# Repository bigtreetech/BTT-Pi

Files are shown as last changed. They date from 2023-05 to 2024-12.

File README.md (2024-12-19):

# BTT-PI
***The usage and configuration of the OS image is exactly the same as CB1 normal version, Please refer to [here](https://github.com/bigtreetech/cb1) to write and configure the OS image***

# 40 Pin GPIO
***BTT-PI and CB1 40pin gpio are different, Please refer to [here](https://github.com/bigtreetech/CB1#40-pin-gpio) for details***

# BTT-PI FAN Pin 

***BIGTREETECH Pi V1.2 Fan Pin connection
Please refer to [here](https://github.com/bigtreetech/BTT-Pi/blob/master/BIGTREETECH%20Pi%20V1.2%20-%20Board%20Fan%20Pin%20Configuration) for details***

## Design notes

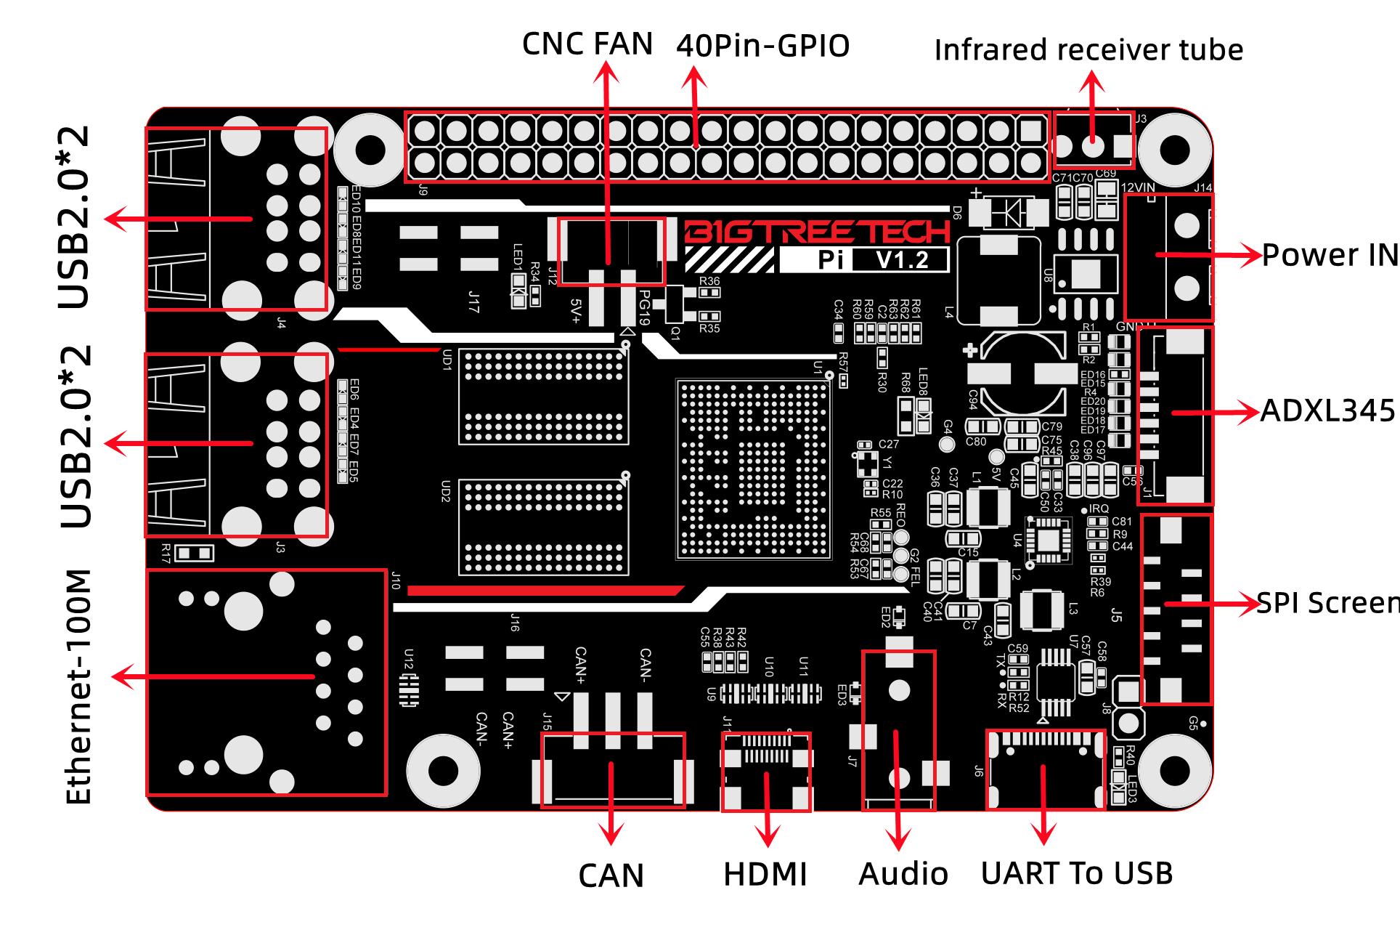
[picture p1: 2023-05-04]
Hardware/Connector.png

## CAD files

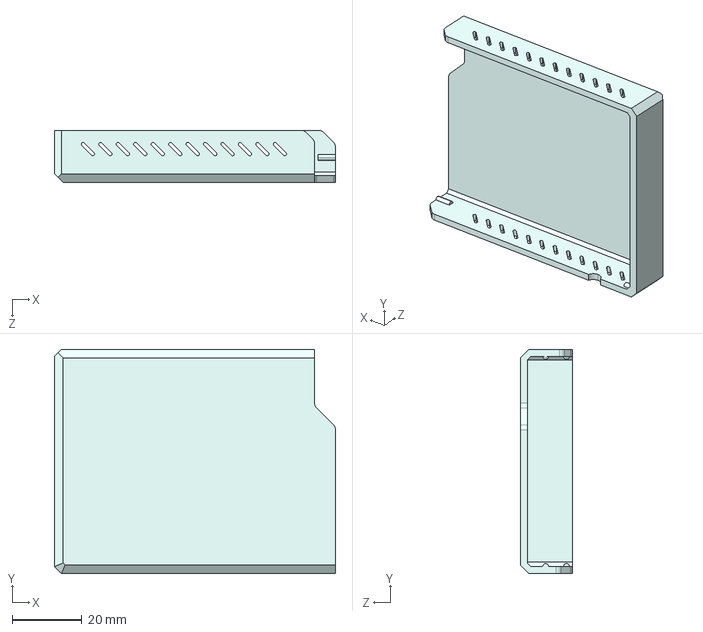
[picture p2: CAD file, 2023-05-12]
3D/BTT_PI_V1.2_Model/step/top_case.STEP
80.5 x 64.2 x 15.0 mm

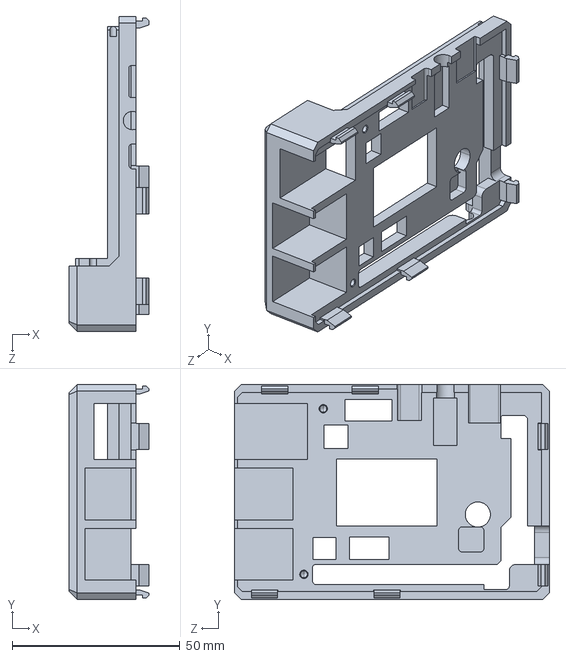
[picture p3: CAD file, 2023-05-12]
3D/BTT_PI_V1.2_Model/step/middle_case.STEP
24.0 x 64.2 x 94.0 mm

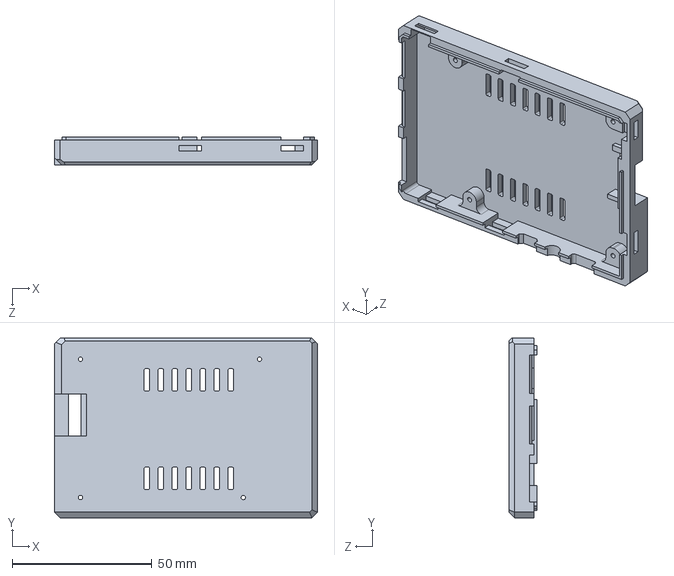
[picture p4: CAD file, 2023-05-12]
3D/BTT_PI_V1.2_Model/step/bottom_case.STEP
94.0 x 64.2 x 10.0 mm

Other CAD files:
3D/BTT_PI_V1.2_Model/stl/bottom_case.STL
3D/BTT_PI_V1.2_Model/stl/middle_case.STL
3D/BTT_PI_V1.2_Model/stl/top_case.STL

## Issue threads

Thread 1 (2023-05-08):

Compatibility with original Raspberry images?

dedekcz, 2023-05-08:
Hello,

Is this board compatible with official Raspberry image?

THX,RH

Tompudex, 2023-05-09:
No, it isn't. the iso that can be used separately for cb modules is also suitable for this

Nbrooks639, 2023-05-19:
i am having issues with reconnecting to mainsail after a simple save and restart from any cfg file. i have to completely shutdown and reboot

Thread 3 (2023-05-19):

Board Fan PG19 pin

So6Rallye, 2023-05-19:
Hi,

I've connected fan on PG19 pin and Klipper doesn't recognize them. Do you have a config to make it work?

error mainsail : Pin 'PG19' is not a valid pin name on mcu 'mcu'

actually I've bypass with one pin on my board but I want to use PG19 pin on BTT PI

[temperature_fan raspberry_pi]
pin: PB6
kick_start_time: 0.8
#shutdown_speed: 0
off_below: 0.1
max_power: 1.0
#fan_speed: 0.6
sensor_type: temperature_host
control: pid
min_temp: -40
max_temp: 85
#max_delta: 5.0
pid_kp: 1.0
pid_ki: 0.5
pid_kd: 2.0
min_speed: 0.1
max_speed: 0.6
target_temp: 38

So6Rallye, 2023-05-19:
If i create and another MCU like this :

[mcu host]
serial: /tmp/klipper_host_mcu

And define :

[temperature_fan raspberry_pi]
pin: host:PG19

I've got message like this : Pin 'PG19' is not a valid pin name on mcu 'host'

So6Rallye, 2023-05-20:
SOLVED !

Message form facebook BTT group [TJ MacLennan]

PG19 is definitely a GPIO pin. It may not be on the 40 pin GPIO header but any input / output pin on the BTT Pi and CB1 is GPIO.

The formula to convert from PG19 to GPIO is:

[(PG - PA)*32] + {Pin Number}

Where PA = 1, PB =2….so PG = 7

So [(7-1)*32] + 19 = 211

Try using GPIO211

The BTT documentation on this is rubbish and lacking.

result :

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

Closed 2023-05-20.

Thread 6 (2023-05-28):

Multiple Printers?

bamboo-eater, 2023-05-28:
Is it possible to connect more than 1 printer to the BTT Pi?  If so are there any documentation on how to do this. Thanks

flavio-costa, 2023-07-31:
yes it is possible, I uploaded klipper using kiauh, there is an option to choose the number of machines to install, it is called instances)

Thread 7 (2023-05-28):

BTT Pi v1.2 case .stl

claidheamohmor, 2023-05-28:
Sajnos a mellékelt kinyomtatható ház elég sok sebből vérzik, a HDMI, audio és tápcsatlakozók lyukainál a "bottom" és "middle" szekcióban kívűl mélyítést kellett készítenem, hogy a csatlakozók műanyag foglalatai elférjenek és a csatlakozók helyesen üljenek be az aljzatokba, illetve az alaplapi JI5 csatlakozó mellyett belül kivágást kellett csinánom, mert vastag a burkolat és nem fér el. A "bottom" fájban az USB csatlakozó melletti bepattintós lyuknál hibás a szerkesztés, illetve a "middle" szekciónak végül a teljes belsejét kivágtam, mert a hűtőborda miatt nem fér el. Sajnos a chip eléggé melegszik, így mindenképpen szükséges a hűtőborda, sőt úgy tűnik, a ventilátort sem lehet megspórolni. Ha valakit érdekel, a módosításokat feltöltöm a Thingiverse-re.

nickdollimount, 2023-06-23:
I also had to make similar modifications. I did the middle cutout for the heatsink as mentioned above, though I didn't have any of the other issues mentioned. The biggest issue for me is a section next to the SD card reader that sits right above one of the tiny components. It wasn't closing right for me so of course my first instinct was to squeeze harder; this piece broke the solder joint of the tiny component. I had to clip out that section of plastic and resolder the component. See the screenshot attached where I circled the offending piece.
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

[BTT Pi Case_Edit.zip](https://github.com/bigtreetech/BTT-Pi/files/11850265/BTT.Pi.Case_Edit.zip)

Escrich, 2024-06-29:
Try mine:

https://www.printables.com/model/927675-caja-para-btt-pi-btt-pi-box-frontal-front

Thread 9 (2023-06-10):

Connecting and spi configuration of SPI ADXL345 on the BTT-PI

Skappa75, 2023-06-10:
Hi, there is a lot of documentation on how to connect an ADXL345 on a CB1 or CM4, and their configuration on Klipper. But I'm in trouble when I connect the BTT-ADXL345 to the BTT-PI by the supplied cable on the dedicated SPI port (page 7 of its manual).
In the pin out what is the right cs_pin number?

Kimmy2000, 2023-06-29:
Hi, this is the setting you require for the BTT-ADXL345 to the BTT-PI

[mcu host]
serial: /tmp/klipper_host_mcu

[adxl345] #BTT PI
cs_pin: host:gpio67
spi_bus: spidev0.0
axes_map: x,y,z

[resonance_tester]
accel_chip: adxl345
accel_per_hz: 70
probe_points: 117.5,117.5,10

In the boardenv.txt uncomment only
overlays=spidev0_0

Skappa75, 2023-06-30:
Hi, thanks for your suggestions but unfortunately it doesn't work by
connecting it via the dedicated ADXL345 port as shown in the BTT-PI manual.
You wrote "cs_pin: host:gpio67" and I noticed that it is from the
40pin-GPIO PC3, you confirm that it is also the right cs.pin of the
dedicated ADXL345 port? Thanks for your help
Skappa

Il giorno gio 29 giu 2023 alle ore 10:59 Kimmy2000 ***@***.***>
ha scritto:

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

Skappa75, 2023-06-30:
I allways recive that error:
"adxl345: spi pins must be on same mcu"

Il giorno gio 29 giu 2023 alle ore 10:59 Kimmy2000 ***@***.***>
ha scritto:

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

Kimmy2000, 2023-06-30:
have you uncommented the SPI like i said here?

In the boardenv.txt uncomment only
overlays=spidev0_0

HYK-HideYourKey, 2023-08-02:
not working for me either... commented spidev0_0 already

UmitBaba, 2023-08-19:
[mcu rpi]
serial: /tmp/klipper_host_mcu

[adxl345]
cs_pin: rpi:gpio67       # I m using fluidd, host:gpio67 doesn't allowed me to write so I tried rpi:gpio67 and just worked.
spi_bus: spidev0.0

[resonance_tester]
accel_chip: adxl345
probe_points:
    155, 155, 20

I m using btt pi v1.2 and this script worked for me. There is one important step, the sd card which plug in to btt pi, you need to plug it your pc and ın the boardenv.txt uncommend overlays=spidev0_0  (remove "#" sign) then dedicated adxl345 port on btt pi works.

Skappa75, 2023-08-19:
Very thanks, I'll try as soon is possible.

Il sab 19 ago 2023, 14:32 UmitBaba ***@***.***> ha scritto:

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

tiagomaricate, 2024-01-23:
What is the name/model of connector in the BTT Pi for the ADXL?

horapet, 2025-04-15:
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

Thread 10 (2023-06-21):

M3 mounting screws cause electrical short

aamott, 2023-06-21:
Issue: There is a positive and negative 12v connection close enough to the mounting screw holes that using an m3 screw instead of an m2.5 screw will cause a short. I found this out when my board started _glowing_ by the mounting hole next to the USB C and smoke came out. Earlier a spark came from the hole on the other side of the SD card.

Since this is a 3D printer board above all and m3 screws fit with minimal resistance, this is a major cause for concern. The fix should be easy though: just add a little more clearance between power and GND.

I would love to recommend this board to my friends, but I can't do that with an easy short right there. Can we get a fix?

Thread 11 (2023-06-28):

Enabling the U2C can adapter

orotecluc, 2023-06-28:
I have bought a BTT-Pi and the U2C pinboard,bt when I assemble them, the PI does not find the canbus...
Is there somewhere an explanation on how to enable the U2C pinboard?

Byourei, 2023-07-06:
Hi, I have a similar problem. I bought a U2C module for the BTT Klipper Pi. Pi does not see U2C when connected, but the LEDs light up. When turned on with BOOT pressed, it can be seen in usb devices, can be flashed. and that's all. we did not find a guide or a manual anywhere. and technical support doesn't know either.

pauluchin, 2023-08-17:
Hi, I also have questions about how to use it. If you could provide more information on how to enable and use it, there isn't much information on the web.

DrKlipper, 2023-09-12:
I had the same issue. Just compile and flash a new firmware and it should work:

- `sudo apt install cmake gcc-arm-none-eabi -y`
- `cd ~`
- `git clone --depth=1 -b stm32g0_support https://github.com/bigtreetech/candleLight_fw`
- `cd ~/candleLight_fw`
- `mkdir build`
- `cd build`
- `cmake .. -DCMAKE_TOOLCHAIN_FILE=../cmake/gcc-arm-none-eabi-8-2019-q3-update.cmake`
- `make budgetcan_fw`
bring CAN Adapter in DFU Mode ... Attach to USB C Cable, hold BOOT button and connect ...
- Flash Adapter : `dfu-util -R -a 0 -s 0x8000000:mass-erase:force -D ~/candleLight_fw/build/budgetcan_fw.bin`

Hoeby, 2024-06-30:
Just to be sure.

Is this for the can adapter v1.0 which is mounted on top of the btt pi? Or for the bigger u2c can adapter V2.1?

orotecluc, 2024-06-30:
For the small v1 that goes on top of pi v1

Verzonden vanaf Outlook voor Android<https://aka.ms/AAb9ysg>
________________________________
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

Hoeby, 2024-06-30:
i ask it here, because there is not much information to find online about this u2c boad.

When i run "lsusb", then i find "OpenMoko, Inc. Geschwister Schneider CAN adapter". It finds the board.
When i run "~/klippy-env/bin/python ~/klipper/scripts/canbus_query.py can0", then i don't see an ID from this board, is this correct? I would say every canbus device must have an ID, also this can adapter.

The reason why, i tried multi can boards to run on the can adapter, but nothing works. Looks like the issue is in the can adapter, but i am not sure

Mati989, 2025-01-17:
Hi. Can someone write what is the full process of flashing this small adapter that goes to the top of pi v1.2 please.I can't find any manual for this adapter.

hiaselhans, 2025-01-23:
@Mati989
https://drklipper.de/doku.php?id=sbcs:61_-_bigtreetech_pi_v1.2_mit_can

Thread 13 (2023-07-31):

i2c overlay

zuverck, 2023-07-31:
Trying to determine which pins on the GPIO are tied to the i2c interface.  There is an overlay and i2c device defined in the BoardEnv.tst file but don't see any documentation or notation in the pins diagram on which pins these are connected to on the GPIO header.

intplus10, 2023-10-17:
It is matching with the standard Pi. I would refer to BTT-Pi user manual page 7, I hope you are searching for this information:
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

EidenPride, 2024-09-08:
> Trying to determine which pins on the GPIO are tied to the i2c interface. There is an overlay and i2c device defined in the BoardEnv.tst file but don't see any documentation or notation in the pins diagram on which pins these are connected to on the GPIO header.

Hi did you find out something about l2c?

BTTJUSTIN, 2024-09-09:
Thanks for making this suggestion. We will discuss it internally and update the documentation if it is approved

Closed 2024-10-18.

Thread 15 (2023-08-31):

Btt pi not working on second day

cheuhyakuroku, 2023-08-31:
Mthe first day it run normal. I config klipper, and print some model file. But second day it not work. Power led is light but nothing happen. Device not turn on,

MarioPerini, 2023-12-22:
same here, waiting for response through mail support

Khalid310, 2024-01-19:
Have you both achieved any solution?

Mine was powered by 24v. The first time its green light was on for a while and then it was suddenly off. Then, each time I power it up, the green light blinks once and totally stops. Tested powering via USB, and it was OK.

MarioPerini, 2024-01-25:
No they declined my refund request on AliExpress. I will. Not buy any BTT products anymore, since I was treated like this. Mine run only for one day at 24V

Escrich, 2024-06-29:
Mine is working since a couple of months ago, without any problem, but I think it's a 5 V fan, not to sure about it now

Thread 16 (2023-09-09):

Fan pin issue

cheuhyakuroku, 2023-09-09:
anyone help me pls 🥹
btt pi v1.2 fan pin issue
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

Escrich, 2024-06-29:
[mcu BTT-Pi]
serial: /tmp/klipper_host_mcu

[temperature_fan BTT-Pi_CPU]  # Temperatura interna del procesador de la BTT Pi
pin: BTT-Pi:gpio211
max_power: 1.0
shutdown_speed: 0
sensor_type: temperature_host
target_temp: 40
max_temp: 85
min_temp: 5
control: pid
pid_kp: 1.0
pid_ki: 0.5
pid_kd: 2.0
off_below: 0.1 # Mantener apagado si la potencia aplicada está por debajo de este valor

Escrich, 2024-06-29:
Check the names you used

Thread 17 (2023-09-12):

Can U2C module not connecting to SB2240

CircuitR, 2023-09-12:
Hi, I have followed the manual for the SB2240, but when I try to flash the SB2240 via Can I get flash error

ERROR:root:Flash Error
Traceback (most recent call last):
  File "/home/biqu/CanBoot/scripts/flash_can.py", line 493, in run_query
    self.cansock.bind((intf,))
OSError: [Errno 19] No such device

During handling of the above exception, another exception occurred:

Traceback (most recent call last):
  File "/home/biqu/CanBoot/scripts/flash_can.py", line 621, in main
    loop.run_until_complete(sock.run_query(intf))
  File "/usr/lib/python3.9/asyncio/base_events.py", line 642, in run_until_complete
    return future.result()
  File "/home/biqu/CanBoot/scripts/flash_can.py", line 495, in run_query
    raise FlashCanError("Unable to bind socket to can0")
FlashCanError: Unable to bind socket to can0

Please advise to fix.

Rivega42, 2025-01-11:
Did you manage to fix it?

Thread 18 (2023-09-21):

Wifi not working when display plugged in

srbjessen, 2023-09-21:
I just got my BTT Pi set up instead of Rpi. Works very well.
But when i plug in my display with Micro HDMI - HDMI cable, the Pi loses connection to wifi.
As soon as i unplug display, the wifi comes back.
Also, the display is heavily flickering and fading in and out.
What could be wrong?

I'm using UART0 (ttyS0) to connect to klipper-mcu.

BTT Pi v1.2
Display: Biqu BX-TFT70

srbjessen, 2023-09-24:
Initial problem solved, turns out the original cable feeding display info and RGB from mainboard was causing interference.
Having removed the cable, the flicker is gone.
But the display is wrong resolution.
I have tried adjusting the "extraargs" in BoardEnv.txt but still wrong

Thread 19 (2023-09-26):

MKS TS35R V2.0

pipech90, 2023-09-26:
Hello everyone I found the[ instructions](https://github.com/Datastore24Kirill/FBGhost6_klipperScreen) for starting the display. There is one but... It is only for ORANGE pi3. Does anyone have the opportunity to fix the driver for our CPU? Or how can it be used?

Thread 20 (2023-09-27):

Enable 1-wire

Puzzl88, 2023-09-27:
How do you enable 1-wire on the BTT-Pi, specifcally for the DS18B20 sensor?

mdvorak, 2023-09-29:
I've created guide how to do that:
https://gist.github.com/mdvorak/2fccca3fa9f76f5a2e11e567797c76d6

Please let me know if it works, or if the guide needs some improvements/fixes. Thanks

Duplicate to https://github.com/bigtreetech/CB1/issues/65 and https://github.com/bigtreetech/CB1/issues/104

Puzzl88, 2023-09-30:
> Please see [bigtreetech/CB1#65 (comment)](https://github.com/bigtreetech/CB1/issues/65#issuecomment-1740552051) for the answer.

biqu@BTT-CB1:~/w1-gpio-cl$ sudo make install
install -m644 w1-gpio-cl.ko /lib/modules/`uname -r`/kernel/drivers/w1/masters
install: cannot stat 'w1-gpio-cl.ko': No such file or directory
make: *** [Makefile:95: install] Error 1

mdvorak, 2023-09-30:
Hmm, maybe I forgot a package, I'll take a look, thanks

Puzzl88, 2023-10-01:
> Hmm, maybe I forgot a package, I'll take a look, thanks

I understood what's the problem.
After LN -s/Lib/Modules/`Uname -r`/Build/Include/Linux W1, you need to execute a command make.

Thanks for the help!

mdvorak, 2023-10-01:
ah, great, I'll update the guide, thanks!

wmetnitz, 2023-10-03:
sorry, i'm a unix newbe - i get the following error:
---
biqu@voron:~/w1-gpio-cl$ **sudo make**
NOTE: ./w1 symlink is already set and will not be updated. Remove it and restart the compilation process in case you want to re-run the kernel sources examination.
NOTE: gen-mast.h was generated
make -C /lib/modules/5.16.17-sun50iw9/build M= modules
make[1]: Entering directory '/usr/src/linux-headers-5.16.17-sun50iw9'
make[2]: *** No rule to make target 'arch/arm64/tools/gen-cpucaps.awk', needed by 'arch/arm64/include/generated/asm/cpucaps.h'.  Stop.
make[1]: *** [arch/arm64/Makefile:173: archprepare] Error 2
make[1]: Leaving directory '/usr/src/linux-headers-5.16.17-sun50iw9'
make: *** [Makefile:13: all] Error 2

mdvorak, 2023-10-03:
Hmm, that is wierd error :-)

mdvorak, 2023-10-04:
I've managed to reproduce it with latest packages, maybe it was caused by some recent system update, I'll investigate it.

mdvorak, 2023-10-04:
@wmetnitz Found it.
`make` needs to be run without `sudo`, for some reason, it messes up env vars and compilation fails to find some files. Also for the compilation itself, sudo should not be really needed.
Guide updated.

_note: `sudo -E make` seems to work file too.`

mdvorak, 2023-10-04:
That was entirely mistake on my side, sorry!
```
echo 'options w1-gpio-cl m1="gdt:71"' | sudo tee /etc/modprobe.d/w1-gpio-cl.conf
echo 'w1-gpio-cl' | sudo tee /etc/modules-load.d/w1-gpio-cl.conf
```
I needed a tester, thanks

wmetnitz, 2023-10-04:
Hi Michal,
thanks, but it doesn't work:

biqu@voron:~/w1-gpio-cl$ echo 'options w1-gpio-cl m1="gdt:71"' | sudo tee /etc/modprobe.d/w1-gpio-cl.conf
options w1-gpio-cl m1="gdt:71"
biqu@voron:~/w1-gpio-cl$ echo 'w1-gpio-cl' | sudo tee /etc/modules-load.d/w1-gpio-cl.conf
w1-gpio-cl
biqu@voron:~/w1-gpio-cl$ sudo modprobe w1-gpio-cl
modprobe: ERROR: could not insert 'w1_gpio_cl': Exec format error
biqu@voron:~/w1-gpio-cl$

wmetnitz, 2023-10-04:
Hi, thanks for your help, but it doesn’t work…

***@***.***:~/w1-gpio-cl$ echo 'options w1-gpio-cl m1="gdt:71"' | sudo tee /etc/modprobe.d/w1-gpio-cl.conf

options w1-gpio-cl m1="gdt:71"

***@***.***:~/w1-gpio-cl$ echo 'w1-gpio-cl' | sudo tee /etc/modules-load.d/w1-gpio-cl.conf

w1-gpio-cl

***@***.***:~/w1-gpio-cl$ sudo modprobe w1-gpio-cl

modprobe: ERROR: could not insert 'w1_gpio_cl': Exec format error

***@***.***:~/w1-gpio-cl$

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

math-milan, 2025-01-02:
Hi, I have trouble finding the kernel headers. I have used the new release with the 6.6.66 Kernel but i only find legacy headers with apt. Do i have to get the headers from the kernel direktly ( from source )?

I am trying this at the moment but so far no luck. Thangs for sugestions

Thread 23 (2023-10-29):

launch BC1 on BTT PI from USB

stepand70, 2023-10-29:
Is it possible to teach BTT Pi to run from USB?

idontknowtom, 2023-11-30:
@stepand70 You mean to run from a USB drive or SSD?

stepand70, 2023-11-30:
> @stepand70 You mean to run from a USB drive or SSD?

USB

idontknowtom, 2023-11-30:
@stepand70 You have to setup with a micro SD card first. Then transfer system over to USB. But the BOOT partition will stay on the micro SD card so you need to keep the card in the BTT Pi. The CB1 and BTT Pi are essentially clones of the Orange Pi Zero 2.

So follow this [guide](https://jamesachambers.com/orange-pi-zero-2-usb-ssd-boot-guide/) and it will work. You won’t find any better performance with a USB thumb drive. In fact the guide says you’ll get worse performance. I tested as well. USB to M.2 SATA SSD works amazing.

stepand70, 2023-11-30:
> @stepand70 You have to setup with a micro SD card first. Then transfer system over to USB. But the BOOT partition will stay on the micro SD card so you need to keep the card in the BTT Pi. The CB1 and BTT Pi are essentially clones of the Orange Pi Zero 2.
>
> So follow this [guide](https://jamesachambers.com/orange-pi-zero-2-usb-ssd-boot-guide/) and it will work. You won’t find any better performance with a USB thumb drive. In fact the guide says you’ll get worse performance. I tested as well. USB to M.2 SATA SSD works amazing.

thanks for the advice! It's not about performance, it's not convenient to take out the SD card when it's in the case, I make copies of CB1 and klipper every 3 days))

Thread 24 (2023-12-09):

Display not working

killrob, 2023-12-09:
Hi all,
i have a PTTPi and a TFT35SPI V2.1, i've connected them with the ribbon cable provided with  monitor.
Klipper and Klipperscreen are installed but the display is all white.
what i'm doing wrong?
this is an extract from log:
`2023-12-09 14:17:20,514 [functions.py:log_start()] - --------------------KlipperScreen Log Start--------------------
2023-12-09 14:17:20,516 [functions.py:log_start()] - KlipperScreen Version: v0.3.7-10-gdd3b255
2023-12-09 14:17:20,516 [functions.py:log_start()] - Python version: 3.9
2023-12-09 14:17:20,935 [config.py:get_config_file_location()] - Passed config (-c): /home/biqu/KlipperScreen.conf
2023-12-09 14:17:20,937 [config.py:__init__()] - Config path location: /home/biqu/KlipperScreen/ks_includes/defaults.conf
2023-12-09 14:17:21,004 [config.py:__init__()] - Configured printers: [
  {
    "Printer": {
      "moonraker_host": "127.0.0.1",
      "moonraker_port": "7125",
      "moonraker_api_key": ""
    }
  }
]
2023-12-09 14:17:21,348 [config.py:create_translations()] - Selected lang: None OS lang: en_US
2023-12-09 14:17:21,350 [config.py:install_language()] - Using system lang
2023-12-09 14:17:21,352 [config.py:install_language()] - Using lang en
2023-12-09 14:17:21,436 [screen.py:__init__()] - Screen resolution: 1024x768
2023-12-09 14:17:21,442 [KlippyGtk.py:__init__()] - Font size: 23.8 (medium)
2023-12-09 14:17:24,534 [screen.py:set_screenblanking_timeout()] - Changing screen blanking to: 3600
2023-12-09 14:17:24,548 [screen.py:set_screenblanking_timeout()] - Using DPMS
2023-12-09 14:17:24,558 [screen.py:initial_connection()] - Default printer: None
2023-12-09 14:17:24,559 [screen.py:connect_printer()] - Connecting to printer: Printer
2023-12-09 14:17:24,559 [screen.py:_load_panel()] - Loading panel: splash_screen
2023-12-09 14:17:24,705 [screen.py:attach_panel()] - Current panel hierarchy: splash_screen
2023-12-09 14:17:24,721 [KlippyWebsocket.py:connect()] - Attempting to connect
2023-12-09 14:17:24,760 [KlippyRest.py:_do_request()] - Sending request to http://127.0.0.1:7125/server/info
2023-12-09 14:17:24,782 [KlippyRest.py:_do_request()] - Sending request to http://127.0.0.1:7125/access/oneshot_token
2023-12-09 14:17:24,784 [KlippyWebsocket.py:connect()] - Starting websocket thread
2023-12-09 14:17:24,800 [_logging.py:info()] - Websocket connected
2023-12-09 14:17:24,801 [KlippyWebsocket.py:on_open()] - Moonraker Websocket Open
2023-12-09 14:17:25,096 [KlippyRest.py:_do_request()] - Sending request to http://127.0.0.1:7125/server/info
2023-12-09 14:17:25,117 [KlippyRest.py:_do_request()] - Sending request to http://127.0.0.1:7125/server/info
2023-12-09 14:17:25,119 [screen.py:init_printer()] - Moonraker info {'klippy_connected': False, 'klippy_state': 'disconnected', 'components': ['klippy_connection', 'application', 'websockets', 'internal_transport', 'dbus_manager', 'database', 'file_manager', 'klippy_apis', 'secrets', 'template', 'shell_command', 'machine', 'data_store', 'proc_stats', 'job_state', 'job_queue', 'http_client', 'announcements', 'webcam', 'extensions', 'octoprint_compat', 'authorization', 'history', 'update_manager'], 'failed_components': [], 'registered_directories': ['config', 'logs', 'gcodes'], 'warnings': [], 'websocket_count': 1, 'moonraker_version': 'v0.8.0-206-g9ad8fed', 'missing_klippy_requirements': [], 'api_version': [1, 4, 0], 'api_version_string': '1.4.0'}
2023-12-09 14:17:25,138 [KlippyRest.py:_do_request()] - Sending request to http://127.0.0.1:7125/server/webcams/list
2023-12-09 14:17:25,141 [printer.py:configure_cameras()] - Cameras: []
2023-12-09 14:17:25,142 [screen.py:init_printer()] - Klipper not connected
2023-12-09 14:17:28,149 [KlippyRest.py:_do_request()] - Sending request to http://127.0.0.1:7125/server/info
2023-12-09 14:17:28,168 [KlippyRest.py:_do_request()] - Sending request to http://127.0.0.1:7125/server/info
2023-12-09 14:17:28,170 [screen.py:init_printer()] - Moonraker info {'klippy_connected': False, 'klippy_state': 'disconnected', 'components': ['klippy_connection', 'application', 'websockets', 'internal_transport', 'dbus_manager', 'database', 'file_manager', 'klippy_apis', 'secrets', 'template', 'shell_command', 'machine', 'data_store', 'proc_stats', 'job_state', 'job_queue', 'http_client', 'announcements', 'webcam', 'extensions', 'octoprint_compat', 'authorization', 'history', 'update_manager'], 'failed_components': [], 'registered_directories': ['config', 'logs', 'gcodes'], 'warnings': [], 'websocket_count': 1, 'moonraker_version': 'v0.8.0-206-g9ad8fed', 'missing_klippy_requirements': [], 'api_version': [1, 4, 0], 'api_version_string': '1.4.0'}
2023-12-09 14:17:28,187 [KlippyRest.py:_do_request()] - Sending request to http://127.0.0.1:7125/server/webcams/list
2023-12-09 14:17:28,188 [printer.py:configure_cameras()] - Cameras: []
2023-12-09 14:17:28,189 [screen.py:init_printer()] - Klipper not connected
2023-12-09 14:17:31,150 [KlippyRest.py:_do_request()] - Sending request to http://127.0.0.1:7125/server/info
2023-12-09 14:17:31,169 [KlippyRest.py:_do_request()] - Sending request to http://127.0.0.1:7125/server/info
2023-12-09 14:17:31,171 [screen.py:init_printer()] - Moonraker info {'klippy_connected': False, 'klippy_state': 'disconnected', 'components': ['klippy_connection', 'application', 'websockets', 'internal_transport', 'dbus_manager', 'database', 'file_manager', 'klippy_apis', 'secrets', 'template', 'shell_command', 'machine', 'data_store', 'proc_stats', 'job_state', 'job_queue', 'http_client', 'announcements', 'webcam', 'extensions', 'octoprint_compat', 'authorization', 'history', 'update_manager'], 'failed_components': [], 'registered_directories': ['config', 'logs', 'gcodes'], 'warnings': [], 'websocket_count': 1, 'moonraker_version': 'v0.8.0-206-g9ad8fed', 'missing_klippy_requirements': [], 'api_version': [1, 4, 0], 'api_version_string': '1.4.0'}
2023-12-09 14:17:31,189 [KlippyRest.py:_do_request()] - Sending request to http://127.0.0.1:7125/server/webcams/list
2023-12-09 14:17:31,191 [printer.py:configure_cameras()] - Cameras: []
2023-12-09 14:17:31,191 [screen.py:init_printer()] - Klipper not connected
2023-12-09 14:17:34,155 [KlippyRest.py:_do_request()] - Sending request to http://127.0.0.1:7125/server/info
2023-12-09 14:17:34,178 [KlippyRest.py:_do_request()] - Sending request to http://127.0.0.1:7125/server/info
2023-12-09 14:17:34,181 [screen.py:init_printer()] - Moonraker info {'klippy_connected': True, 'klippy_state': 'startup', 'components': ['klippy_connection', 'application', 'websockets', 'internal_transport', 'dbus_manager', 'database', 'file_manager', 'klippy_apis', 'secrets', 'template', 'shell_command', 'machine', 'data_store', 'proc_stats', 'job_state', 'job_queue', 'http_client', 'announcements', 'webcam', 'extensions', 'octoprint_compat', 'authorization', 'history', 'update_manager'], 'failed_components': [], 'registered_directories': ['config', 'logs', 'gcodes'], 'warnings': [], 'websocket_count': 1, 'moonraker_version': 'v0.8.0-206-g9ad8fed', 'missing_klippy_requirements': [], 'api_version': [1, 4, 0], 'api_version_string': '1.4.0'}
2023-12-09 14:17:34,202 [KlippyRest.py:_do_request()] - Sending request to http://127.0.0.1:7125/server/webcams/list
2023-12-09 14:17:34,204 [printer.py:configure_cameras()] - Cameras: []
2023-12-09 14:17:34,241 [KlippyRest.py:_do_request()] - 404 Client Error>>Not Found for url>>http://127.0.0.1:7125/printer/info
2023-12-09 14:17:37,147 [KlippyRest.py:_do_request()] - Sending request to http://127.0.0.1:7125/server/info
2023-12-09 14:17:37,168 [KlippyRest.py:_do_request()] - Sending request to http://127.0.0.1:7125/server/info
2023-12-09 14:17:37,170 [screen.py:init_printer()] - Moonraker info {'klippy_connected': True, 'klippy_state': 'startup', 'components': ['klippy_connection', 'application', 'websockets', 'internal_transport', 'dbus_manager', 'database', 'file_manager', 'klippy_apis', 'secrets', 'template', 'shell_command', 'machine', 'data_store', 'proc_stats', 'job_state', 'job_queue', 'http_client', 'announcements', 'webcam', 'extensions', 'octoprint_compat', 'authorization', 'history', 'update_manager'], 'failed_components': [], 'registered_directories': ['config', 'logs', 'gcodes', 'config_examples', 'docs'], 'warnings': [], 'websocket_count': 1, 'moonraker_version': 'v0.8.0-206-g9ad8fed', 'missing_klippy_requirements': [], 'api_version': [1, 4, 0], 'api_version_string': '1.4.0'}
2023-12-09 14:17:37,186 [KlippyRest.py:_do_request()] - Sending request to http://127.0.0.1:7125/server/webcams/list
2023-12-09 14:17:37,188 [printer.py:configure_cameras()] - Cameras: []
2023-12-09 14:17:37,208 [KlippyRest.py:_do_request()] - Sending request to http://127.0.0.1:7125/printer/info
2023-12-09 14:17:37,332 [KlippyRest.py:_do_request()] - Sending request to http://127.0.0.1:7125/printer/objects/query?configfile
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

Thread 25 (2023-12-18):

Unable to run ADXL345 from 40 GPIO pins

Vicepredator, 2023-12-18:
Hi, i have a BTT-PI V1.2 and i'm trying to wire the ADXL345 sensor to the GPIO pins.

This is my configuration
```
[mcu rpi]
serial: /tmp/klipper_host_mcu

[adxl345]
cs_pin: None
spi_bus: spidev1.2

[resonance_tester]
accel_chip: adxl345
probe_points: 117.5,117.5,10
```

I've wired the sensor as follows
```
VCC -> 3.3V (Yellow pin)
GND -> GND (Black pin)
CS -> PG12
SDO -> PH8
SDA -> PH7
SCL -> PH6
```

I've tried with all the spi_bus in BoardEnv.txt, but nothing, it doesn't work.

Any clue?

Tankpadua, 2024-01-13:
Why use the GPIO pins when the BTT Pi have the SPI port for the ADXL345 sensor?

Vicepredator, 2024-01-14:
Because I would like to use a standard Amazon sensor, and I don't wanna buy the specific connector.

Gurkenfisch, 2024-01-20:
Just connect it via the dedicated SPI port on the BTT-Pi I have just done that and it works.

mrvander18, 2024-02-20:
Yes, but how. There is no pinout that I can find that matches the BTT-Pi User Manual to the ADXL345.

User Manual ADXL345 Port Pinout
5V
GND
PC3
PC0
PC2
PC4

Board Pinout
GND
VCC
CS
INIT1
INIT2
SDO
SDA
SCL

Now the GND and VCC(5v) are easy enough and from GPIO pinout diagrams, one can deduce the INIT pins are ignored. But HOW do the PC pins map to CEO, Serial Data In, Out and Clock?

**User Manual >> Board**
5V >> VCC
GND >> GND
PC3 >> ??
PC0 >> ??
PC2 >> ??
PC4 >> ??

Amazon Generic Board:
https://www.amazon.com/gp/product/B0BXWHTXWT/ref=ppx_yo_dt_b_search_asin_title?ie=UTF8&psc=1

Gurkenfisch, 2024-02-20:
Ok so I have hooked it up via following:

5V >> VCC
GND >> GND
PC3 >> CS
PC0 >> SCL
PC2 >> SDA
PC4 >> SDO

And then in Klipper I have set it up like the following:

[adxl345] #BTT PI
cs_pin: host:gpio67
spi_bus: spidev0.0
axes_map: x,y,z

[resonance_tester]
accel_chip: adxl345
accel_per_hz: 70
probe_points: 60,60,10

I am almost certain that I just followed the normal input shaper install instructions from there. I am not 100% sure though. It works for me with that wiring.

Vicepredator, 2024-03-08:
Thanks, that seems good.

Vicepredator, 2024-03-08:
Thanks, that seems good.

Hajto, 2024-05-28:
I am having the same issue. Connected the board as in the chart above. No luck klipper detecting the adxl tho

Closed 2024-03-08.

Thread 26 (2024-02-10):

Wifi cable connector name?

Tankpadua, 2024-02-10:
I'm looking for an extension cable for mount a external wifi antenna. I brought one bit the connector are too small. I need with one head SMA.
Thanks

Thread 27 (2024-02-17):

Unnecessary LOGO component in every part of the v1.2 step file.

ChrisJones79, 2024-02-17:
The step file takes a very long time, relatively, and I realized that every `Designatorxxx` tag has a sub-part of a text logo, called `LOGO?xxx`.

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

These are made up of letters, shown here:
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

and here:
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

These are in every single part! Please remove them.

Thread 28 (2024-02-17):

PRODUCT WARNING! DO NOT BUY!

MarioPerini, 2024-02-17:
The product died after just ONE DAY of use. As you can see on issues here on github and on other parts of the internet, i'm by far not the only one with the same problem. So i was sure BTT will replace or refund it fairly quick, but i was so wrong.
"Support" if you can call them so, always promises to replay in a few days and then just silence.
After at least 4 contacts I now just give up my money and throw that board away. My time invested in this case is by far more worth than this SBC!
Company doesn't want to replace or refund, with no further explanation. So my conclusion is to stay away from Big Tree Tech if you want high quality or any usable support if something goes wrong.

Be assured i will never ever purchase any BTT product again!

MarioPerini, 2024-02-21:
Now, out of the blue i got a refund... connected to this issue?

Closed 2024-02-21.

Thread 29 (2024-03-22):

BTT Pi v1.2 very odd USB behaviour.

Bunik, 2024-03-22:
Hello,
I just received Btt Pi v1.2 and hooked it up with Octopus Pro and U2C.
Now the problems.
BTT Pi communicates with Octopus ony with the original USB C cable. Any other C cable I have got does not work and lsusb does not show anything.
U2C does not appear on the list even with that cable. I cannot see it.
When connecting one device at the time.
I also tried to hook up the SB2209 / SBB2240 so I can update the firmware. It does not see it and it does not light the ligts on it.
Even when using the same cable as for the Octobus.

Now the fun part. I used any other cable with the U2C, or the SB2209 and it works with my laptop. Windows immedietely sees the device and I can even put them to DFU mode.  All LEDs on both devices also light up correctly.

It looks like a fault of the Pi, but I have no idea how to resolve it. If it is even possible.
Thanks in advance for any advice!

Bunik, 2024-03-23:
Update:
I have been testing this further and sometimes, just sometimes the U2C lit up when I turned on power to the BTT Pi.
After unplugging and plugging it in again to turn it to DFU mode it did light up again.
Turning on/off the PI sometimes helped, sometimes the U2C just flashed diodes for a second.
I wondered if there is something with the 5V line. So I disconnected the Sunon 5V 0.38W (MF25100V2-1000U-A99) fan which did not work on the PI anyway (It works on the Octopus 5V fan though)
And suddenly all the problems went away?  Now I can use all the cables to connec to all the devices at the same time and they stay on even when I re-connect them.

So I plugged the fan in again to reproduce the issue. I cannot reproduce it again. The fan is still off though.

I am baffled what is going on with this. I will keep testing this board later when I full configure Klipper on it to see how it behaves with a heavy load. I will probably have to wire the 5V fan somewhere else to keep the board cool, which is a bit annoying.

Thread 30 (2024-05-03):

Connectors BOM

turdusmerula, 2024-05-03:
Hello, can you provide the reference of the connectors used on the board?

I'm searching for the exact reference of the CAN connector, I can't find it anywhere

idontknowtom, 2024-05-23:
@turdusmerula It isn't easily found but the CAN connector is a JST XH 3P connector. It is slightly different that what you would find on most 3D printer boards but it still has the same functionality / locking mechanism.

I found this in the STEP file and clicked on the connector in Fusion 360.

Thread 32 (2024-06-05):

Accessing GPIO Pins via Python

tpfirman, 2024-06-05:
Hi, I have bought several BTGT Pi v.12 devices. I am using 2 of them as host machines for CNC/Klipper and they are great.

However, I now have a maker project outside of CNC/3d Printing that I would like to use one for, but I need to access the GPIO pins via Python. Specifically, I need to output on 3 pins, and read from at least two.

I can't seem to find how this is done. Can you please let me know the basics of how I can read/write from/to the GPIO pins using python?

bigtreetech, 2024-06-05:
https://pypi.org/project/gpiod/

https://www.klipper3d.org/RPi_microcontroller.html#optional-identify-the-correct-gpiochip <-- From the klipper wiki but still useful in identifying the gpio.

Closed 2024-06-05.

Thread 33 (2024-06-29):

Independent fan control

Escrich, 2024-06-29:
Dear all, I have one of my BTT Pi inside a Klipper machine, working with the code you provided to make the fan run, without any problem, but, I have a concern, when you are developing something, or simply you will not use this BTT-Pi for klipper, the fan remains stopped, and maybe the CPU will become hot, then, from my point of view, could be a great idea to have something similar as the Raspberry pi has, in order to control the fan in a regulated way, directly as a part of the OS, enclosed I send you three pictures in order to explain what I mean:

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

Escrich, 2024-07-03:
Just doing this control, will be a good idea to make a proportional control, instead of the simple on/off control that Raspberry have

PhilippeLafargue, 2024-09-17:
You are right. Actual solution is klipper dependent: fan can be controlled by klipper only.

But fan control should be OS dependent, as it is related to the MCU cooling, klipper running or not. There are existing solutions for Raspberry PI that could be adapted to BTT-PI.

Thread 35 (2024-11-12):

Not working at all, pls help

HelioNM, 2024-11-12:
I purchase a new BTT Pi 1.12.

I followed the instructions, burn the iso provided here to an SD, edit the config to give the SSID and password, insert SD at the BTT and.... Nothing happen, no connection.

I tried to even use a open wifi network, 3 diferent router, even I tried to share the wifi of my phone, nothing happen, the BBT not connect so I can acces it, I dont know even if it is working or not.

The green led is ON and still. I tried to power it using USB-C cable and also using a 12V PSU of my printer. Nothing.

Help pls.

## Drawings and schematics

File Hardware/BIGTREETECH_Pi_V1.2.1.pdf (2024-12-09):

# 深圳市必趣科技有限公司

Title BIGTREETECH_Pi_V1.1 | Design Bron Bai
Size A3 | Document Number 01_Cover Page | Rev V1.1
Date: Tuesday, November 15, 2022 | Sheet 1 of 16

# BIGTREETECH_Pi_V1.2.1

# 深圳市必趣科技3D打印机BTTPi项目

# SOC: _H616 DDR: _D2516ECMDXGJD MODULE: _TL8189FCB DCDC: _AXP313A LDO: _ XC6220B331MR-G

# 深圳市必趣科技有限公司

Title BIGTREETECH_Pi_V1.1 | Design Bron Bai
Size A3 | Document Number 02_Index | Rev V1.1
Date: Tuesday, November 15, 2022 | Sheet of 2 16

# BIGTREETECH_Pi_V1.1_221114

# 01_Cover Page 02_Index 03_Function Block Diagram 04_Revision History 05_SoC_PMU 06_SOC_BT-WIFI 07_SOC_HDMI_ETH_USB_POWER 08_SOC-DDRCTR_LPDDR3 32X1 09_IO-LDO-FAN 10_BT-WIFI_Module 11_USB To UART 12_SoC_TF_CARD 13_HDMI2.0 14_100M-Ethernet 15_HOST-USB 16_AUDIO-VIDEO-IR

# 深圳市必趣科技有限公司

Title BIGTREETECH_Pi_V1.1 | Design Bron Bai
Size A3 | Document Number 03_Function Block Diagram | Rev V1.1
Date: Tuesday, November 15, 2022 | Sheet of

# TL8189FCB

# SDIO1

# 16BIT_256M 24MHz

RJ45
100M

# SPI0

# SCL0

AXP1530A | SDA0

# AP-RESET PWRON

# FEL RECOVERY DBUG_TX DBUG_RX

# DLDO1_3V3/300mA

# ALDO1_1V8/200mA

# LX2_CPU/1.8A

# LX1_GPU+SYS/1.6A

# LX3_DRAM/1.8A

H616

3.3V

# XC6220B331MR-G

# LDO XC6220B331MR-G

# LDO

WIFI | IO-VCC

# PHONE

# DCDC 12VTO5V/3A

# HDMI

MODULE | USB UART TO
DDR3x2 | IR
SPI1 | SPI0
DSI | Acceler

# USB OTG HOSTUSB2

# HOSTUSB1 HOSTUSB3

J7 | J11 | U6 | J6 | J10 | J3 | J4
J5 | J1 | UD1&UD2 | U3 | Y1

12V/2A

U8 | J14
U5 | U2

U4

# 深圳市必趣科技有限公司

Title TREETECH_Pi_V1.1 | Design
| 04_Revision History

# 版本历史

版本 | 日期 | 修改者 | 修改说明 | 批准
V1.0A | 2022.07.05 | Byron Bai | 1. 在CB1_V2.1设计上修改。
V1.0 | 2022.08.01 | Byron Bai | 2. 增加网口，增加HDMI,增加HOST-USB。 3. IO口全部拉出来。 4. 增加SPI屏和加速计接口。 1. 调换WIFI的方向，天线向这USB那边。
V1.1 | 2022.09.01 | Byron Bai | 2. CH340灯接在芯片输出端。 3. 更改ESD5341N的封装。 1.调换WIFI的方向，天线向耳机这边。
Pi V1.1 | 2022.11.14 | Wan gz | 2.CH340供电接在TYPEC输入端。 3.更改WIFI供电 LDO 为 XC6220B331MR-G。 1.PCB优化走线，SCH同步更新文件名 4.取消PG6 PG7 PG8 PG9，更改为PI5 PI6 PI9 PI10。 5.WIFI SDCARD SDIO增加上拉做等长。 6.TF-CARD SDIO做等长。 7.增加WIFI电源滤波和磁珠。 8.增加DCDC电源滤波。 9.增加系统灯。

1V8

3V3

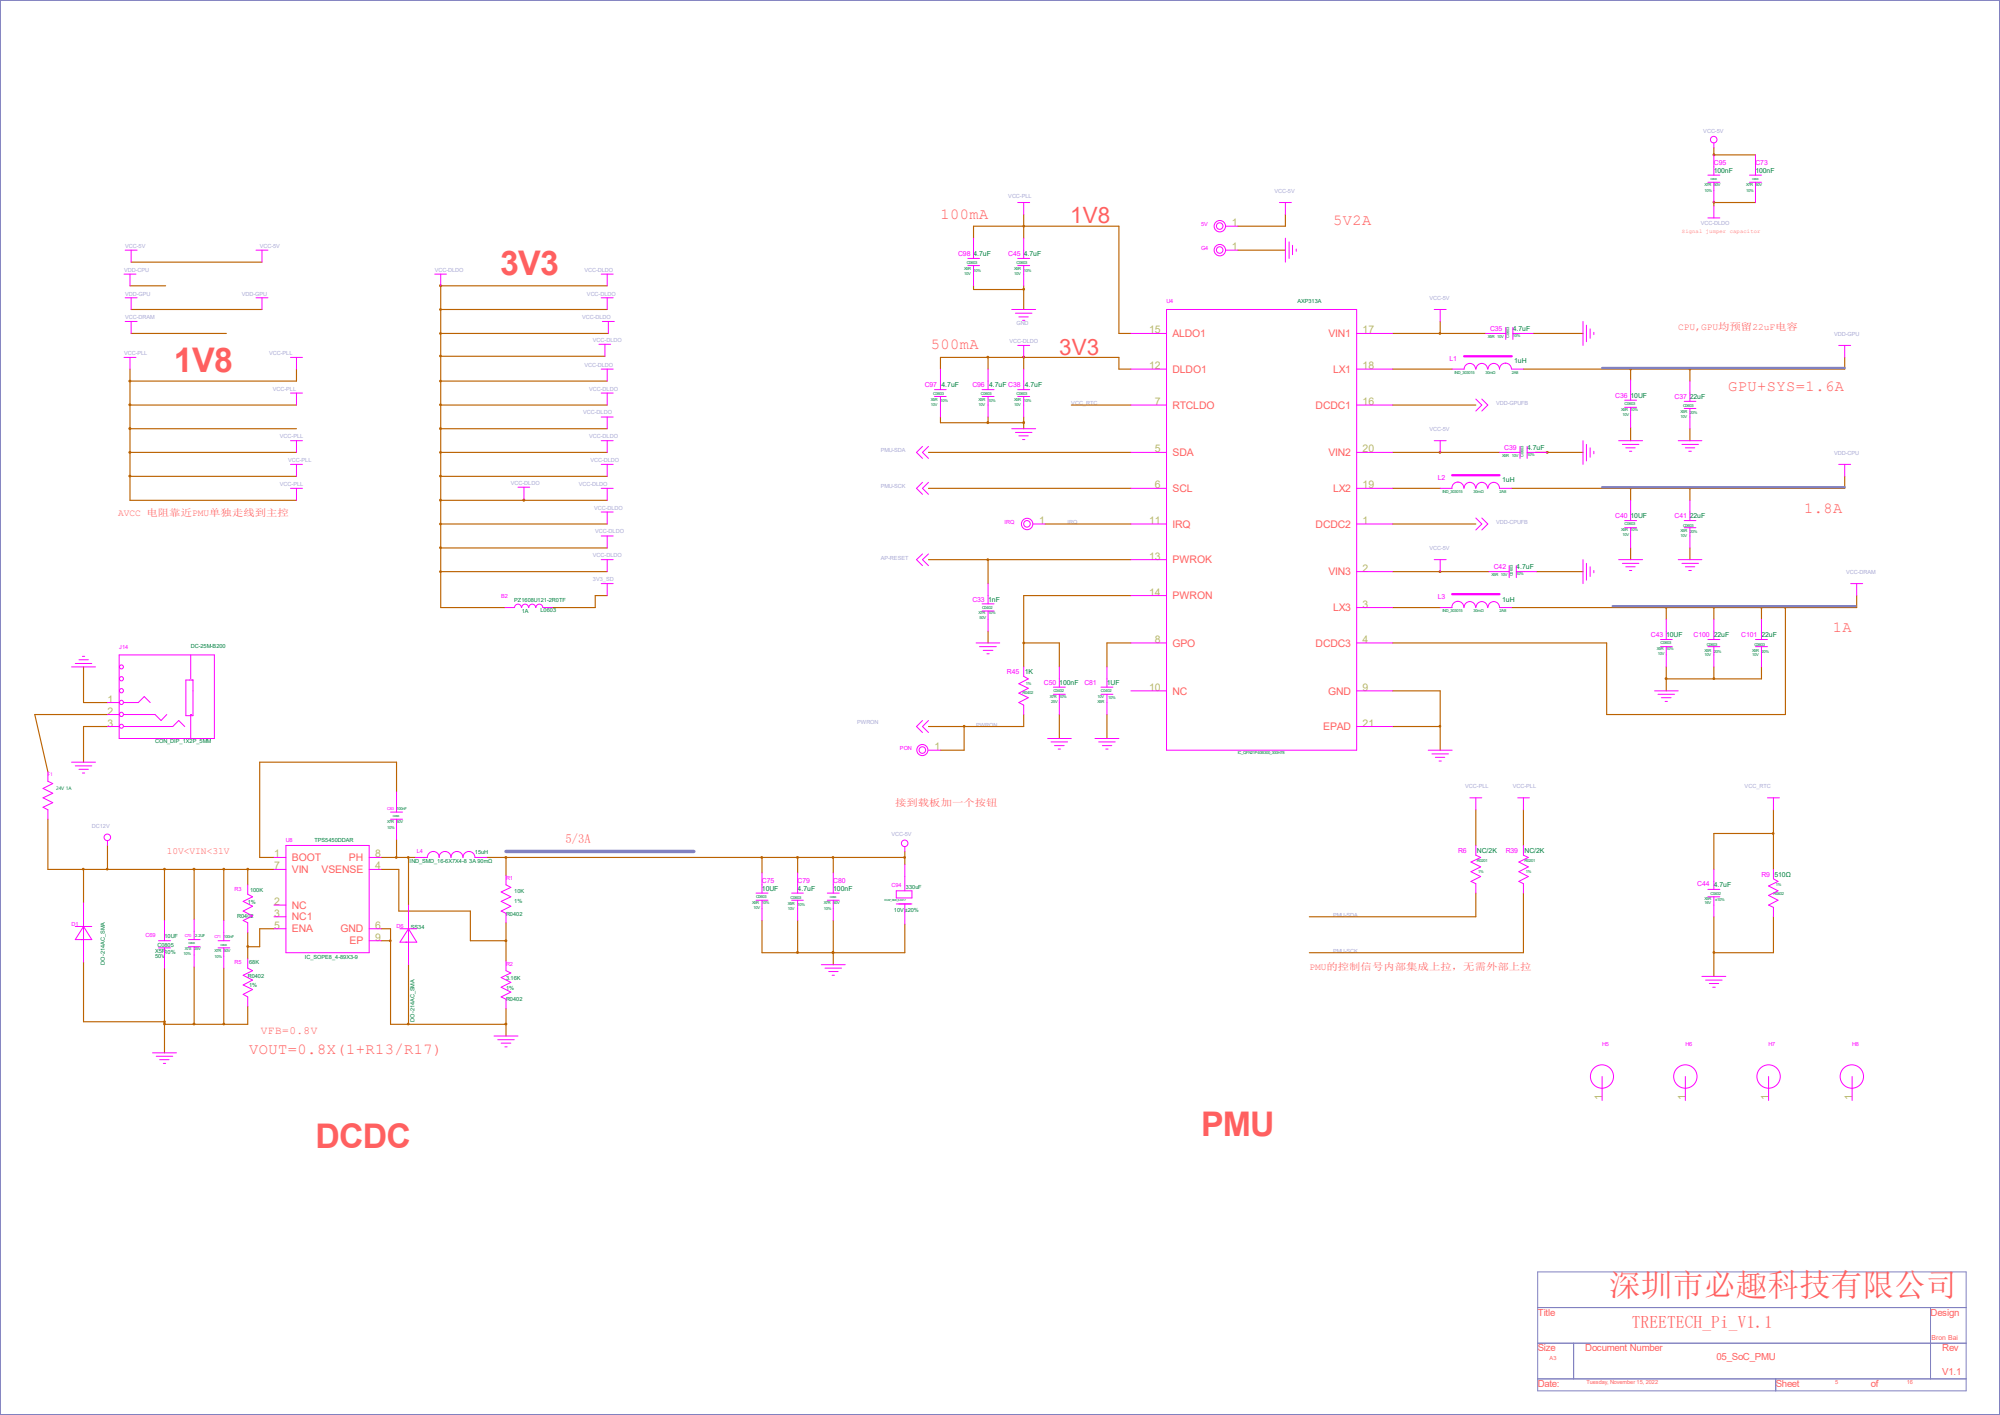
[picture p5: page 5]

Title TREETECH_Pi_V1.1 | Design

05_SoC_PMU

## UART0_DBUG

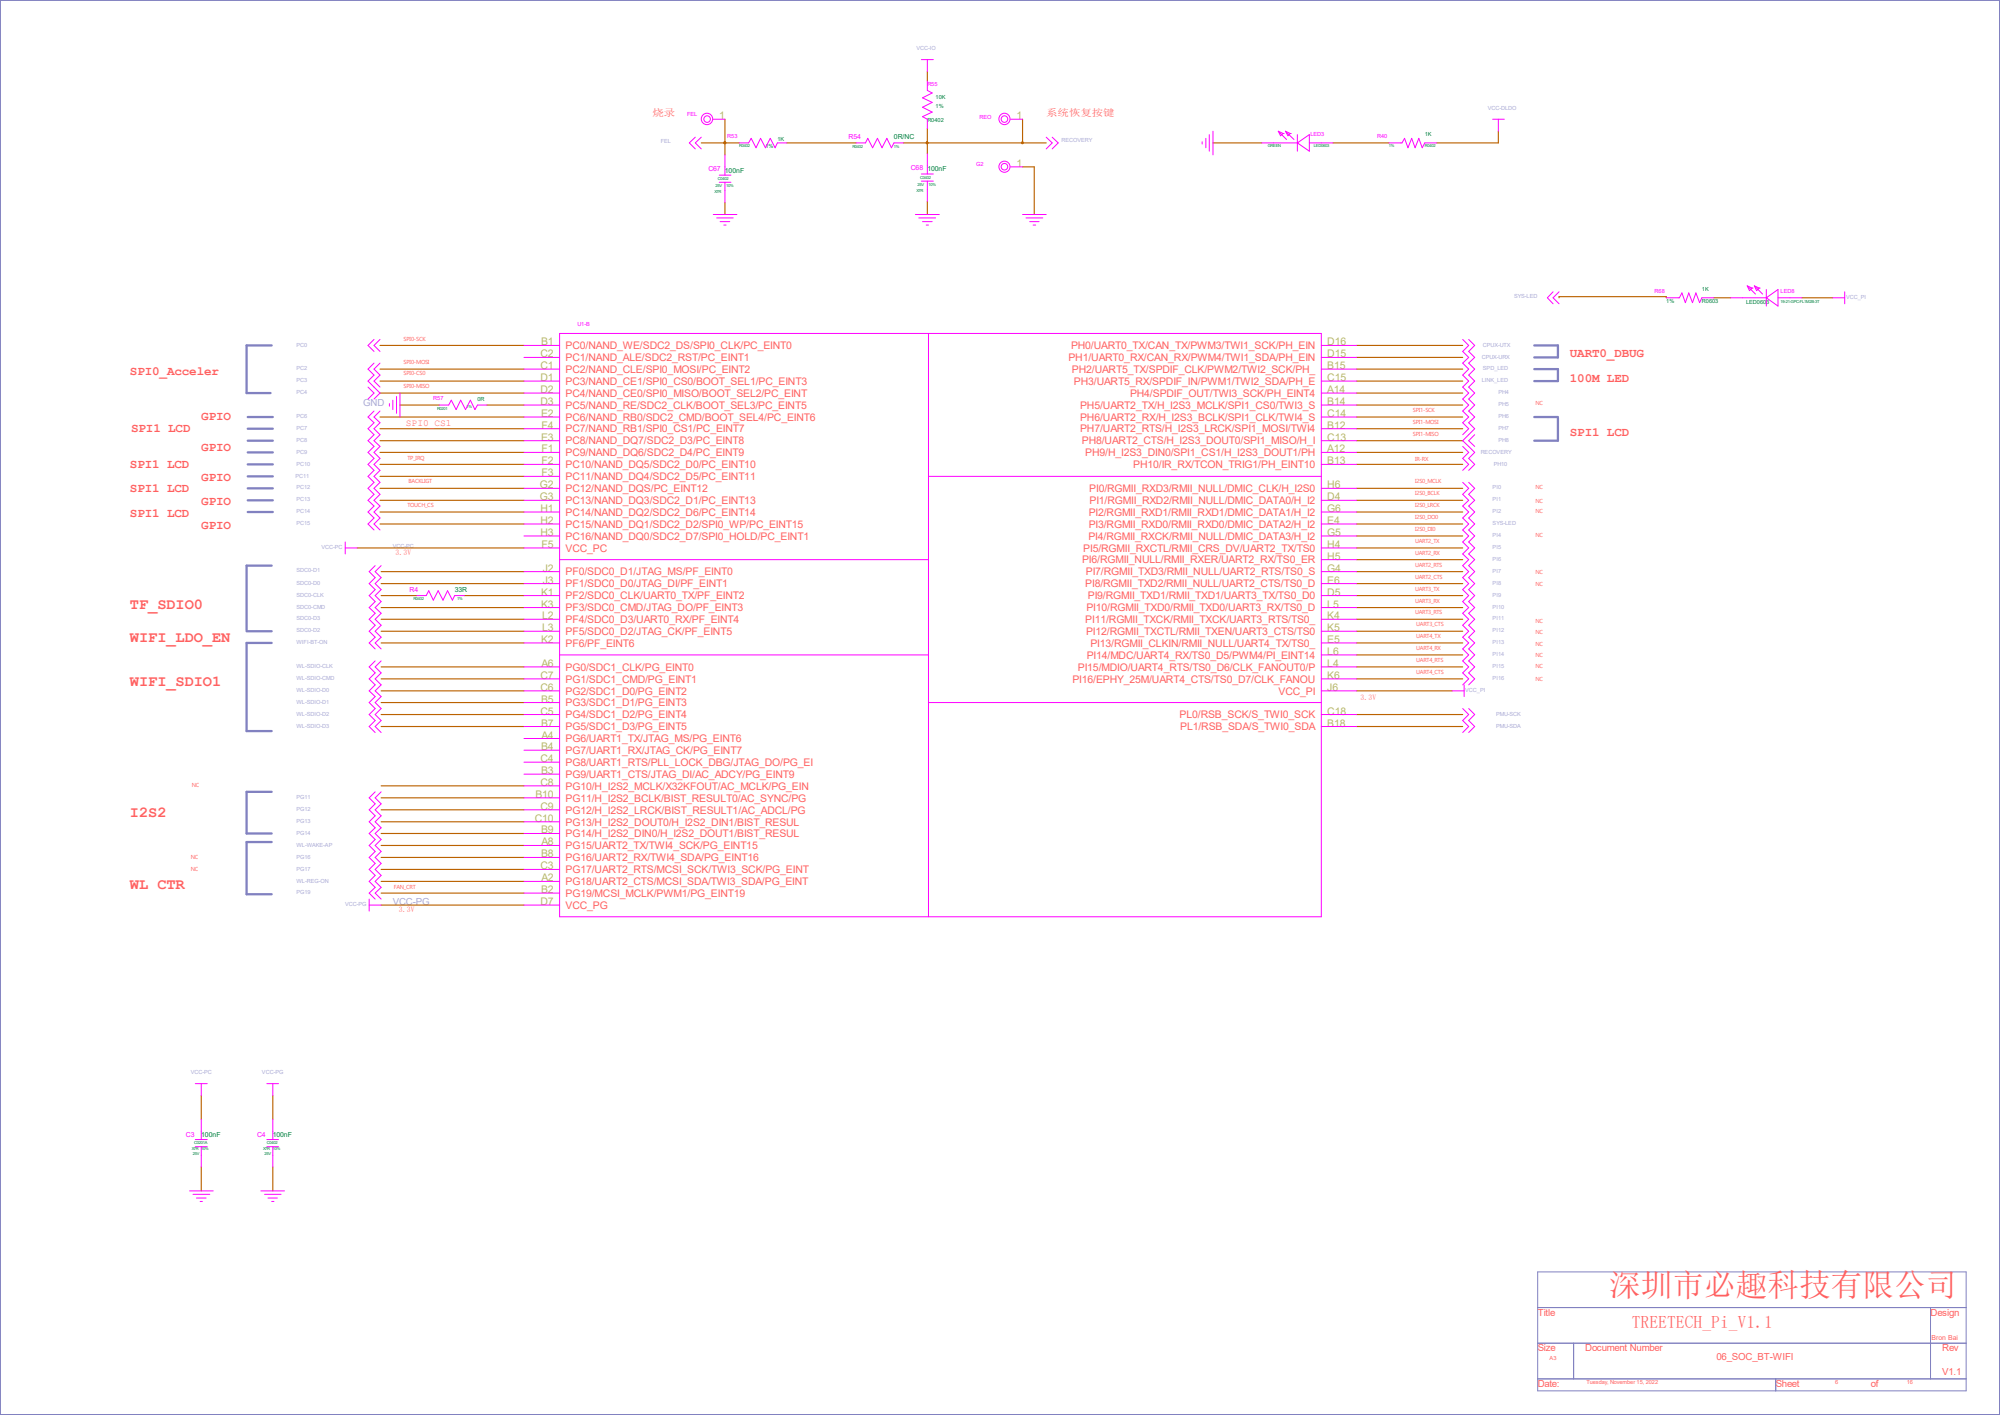
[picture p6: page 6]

K2 A4 B4 C4 B3 C8 | | H5 UART2_RX
PF0/SDC0_D1/JTAG_MS/PF_EINT0 PF1/SDC0_D0/JTAG_DI/PF_EINT1 PF2/SDC0_CLK/UART0_TX/PF_EINT2 PF3/SDC0_CMD/JTAG_DO/PF_EINT3 PF4/SDC0_D3/UART0_RX/PF_EINT4 PF5/SDC0_D2/JTAG_CK/PF_EINT5 PF6/PF_EINT6 | G4 UART2_RTS

Title TREETECH_Pi_V1.1 | Design

06_SOC_BT-WIFI

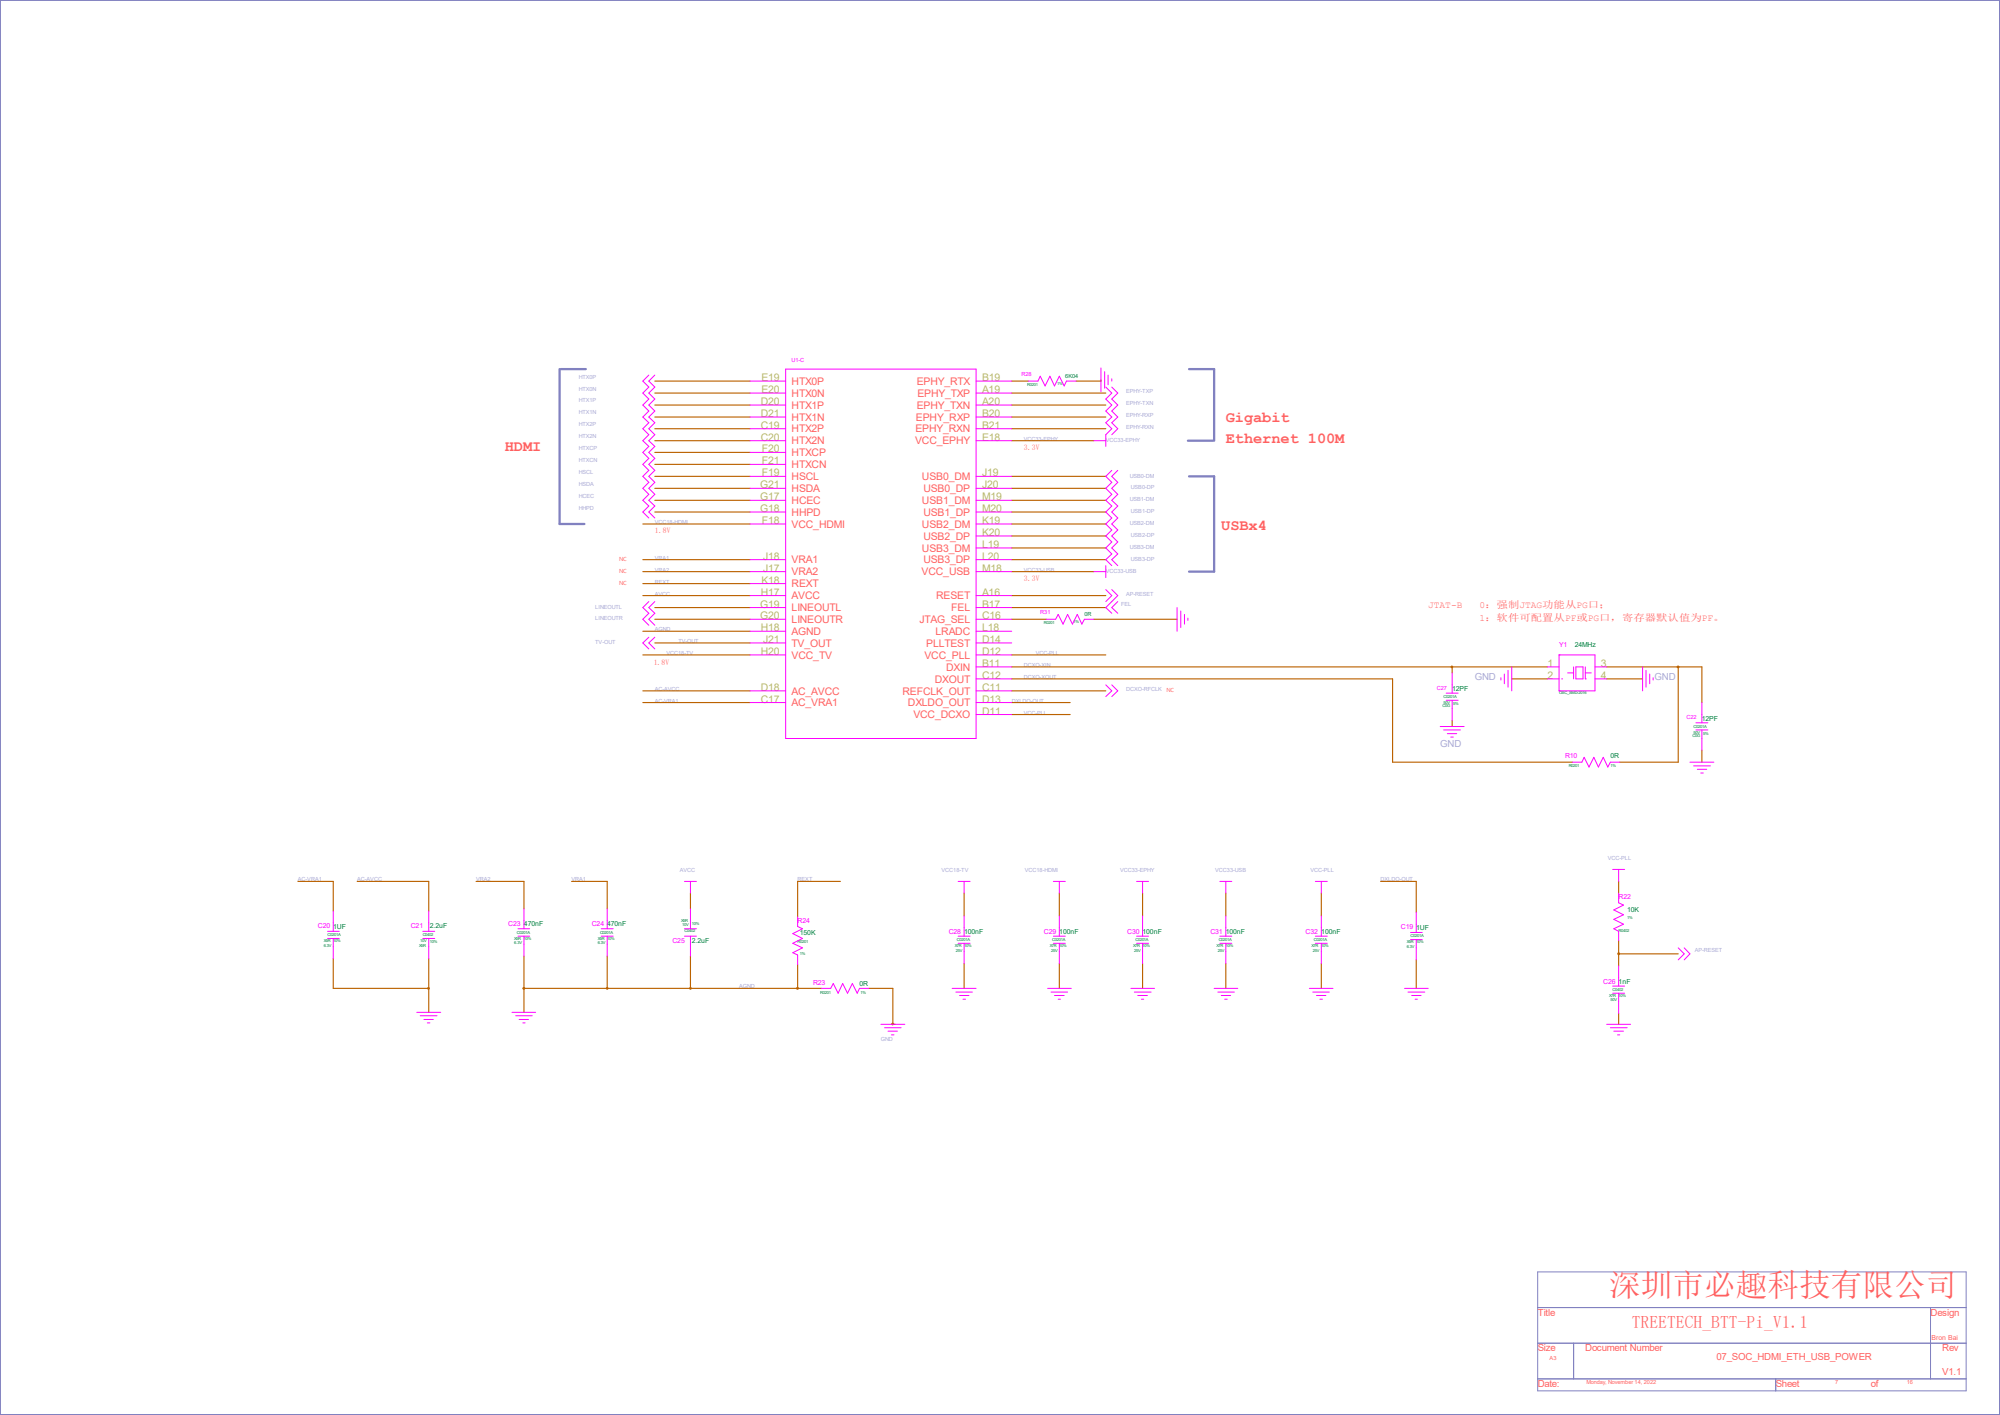
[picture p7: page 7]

Title TREETECH_BTT-Pi_V1.1 | Design

07_SOC_HDMI_ETH_USB_POWER

Monday, November 14, 2022

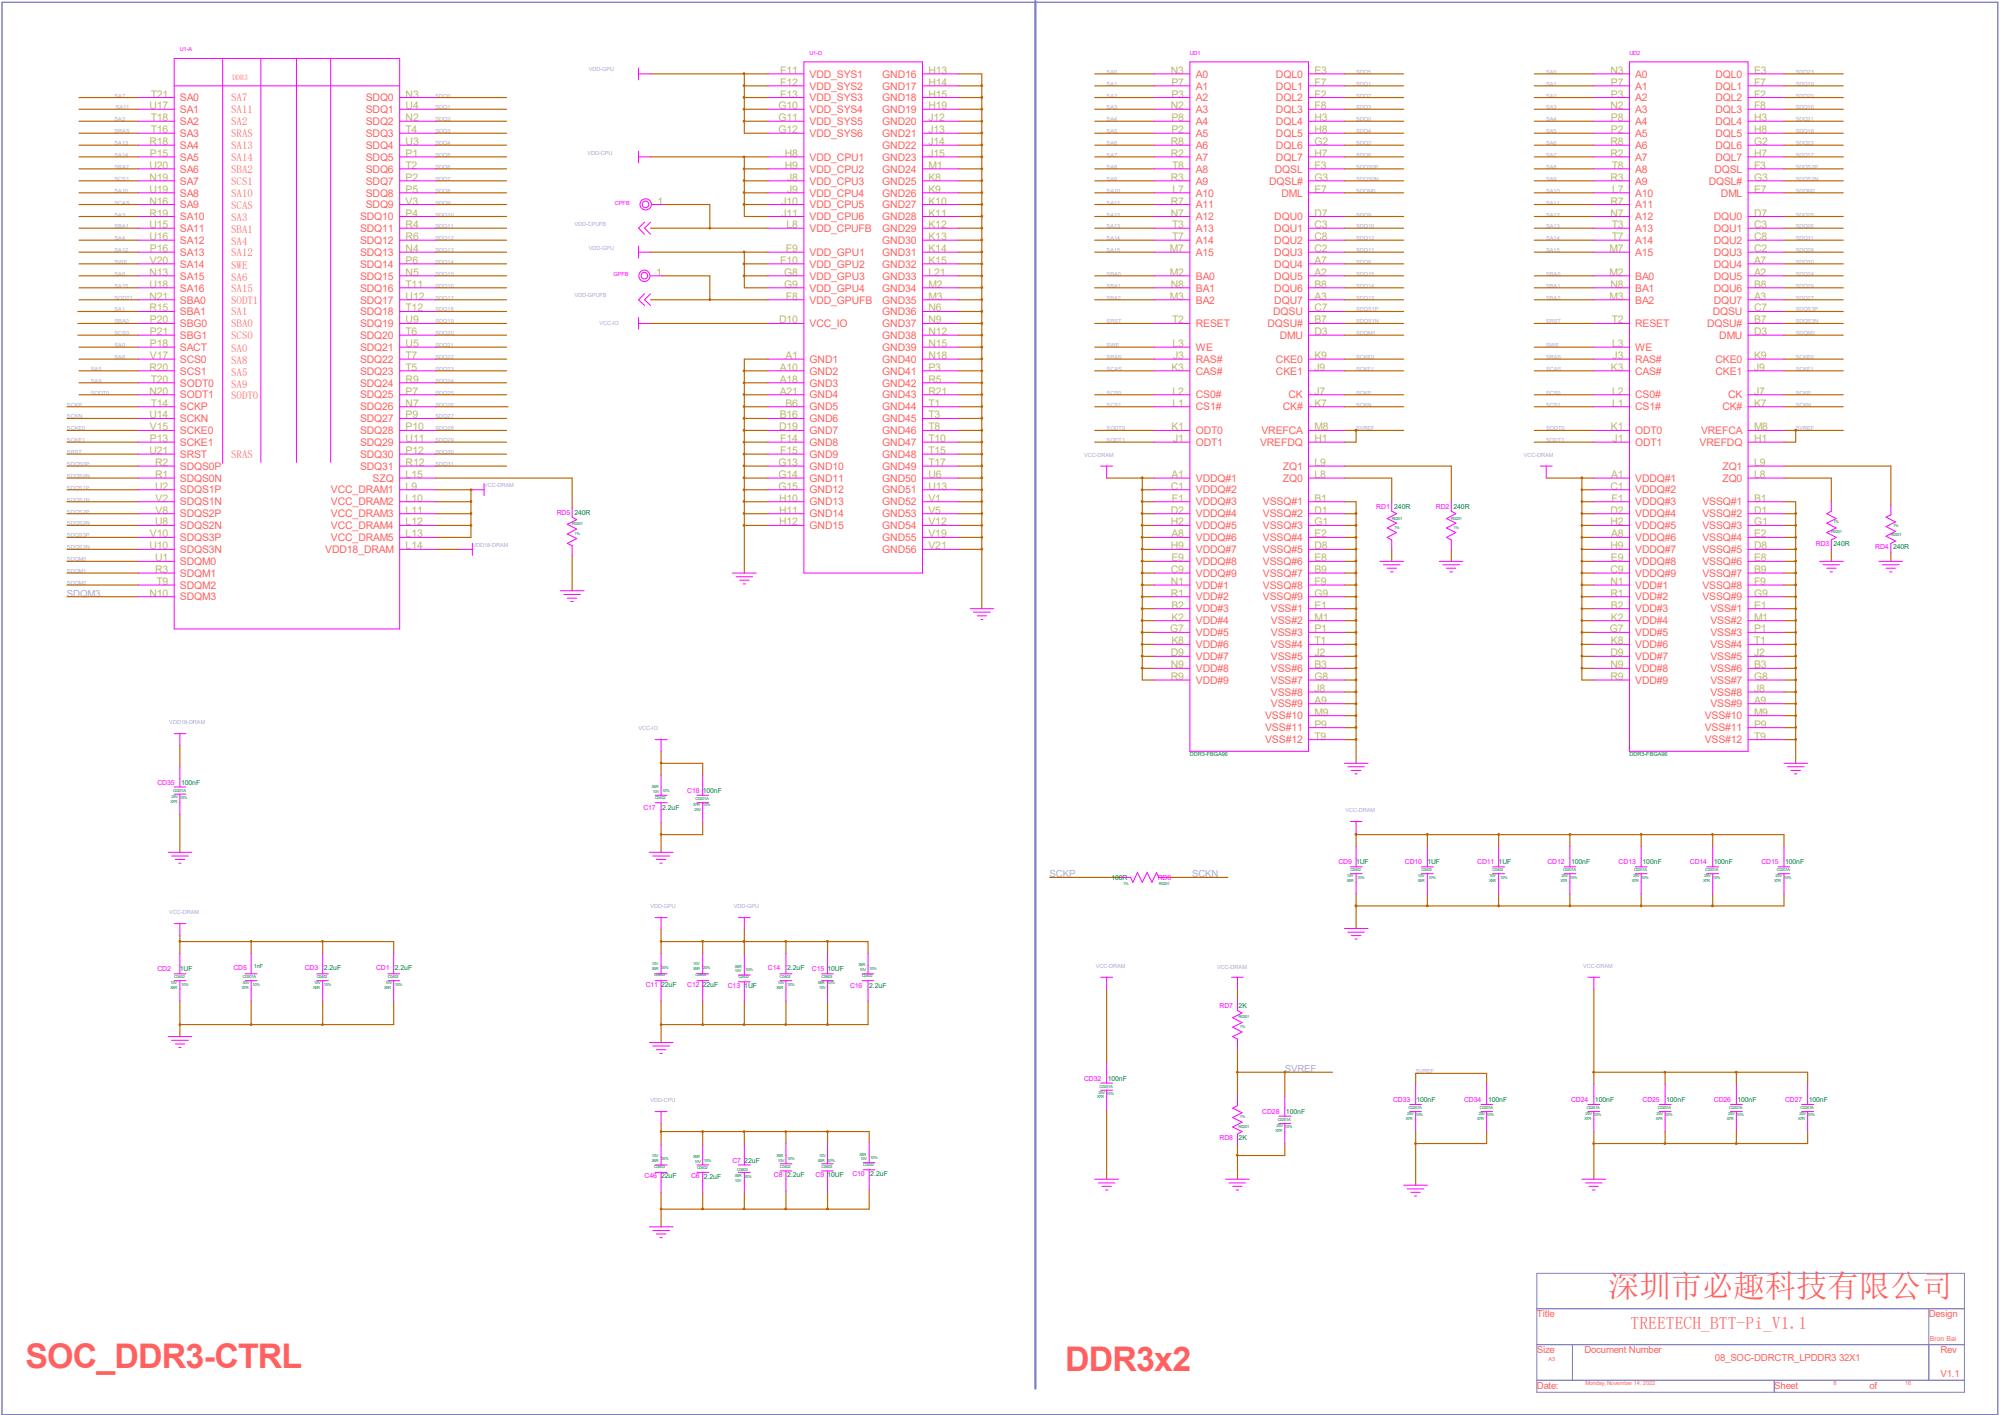
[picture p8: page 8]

DDR3

Title TREETECH_BTT-Pi_V1.1 | Design

08_SOC-DDRCTR_LPDDR3 32X1

Monday, November 14, 2022

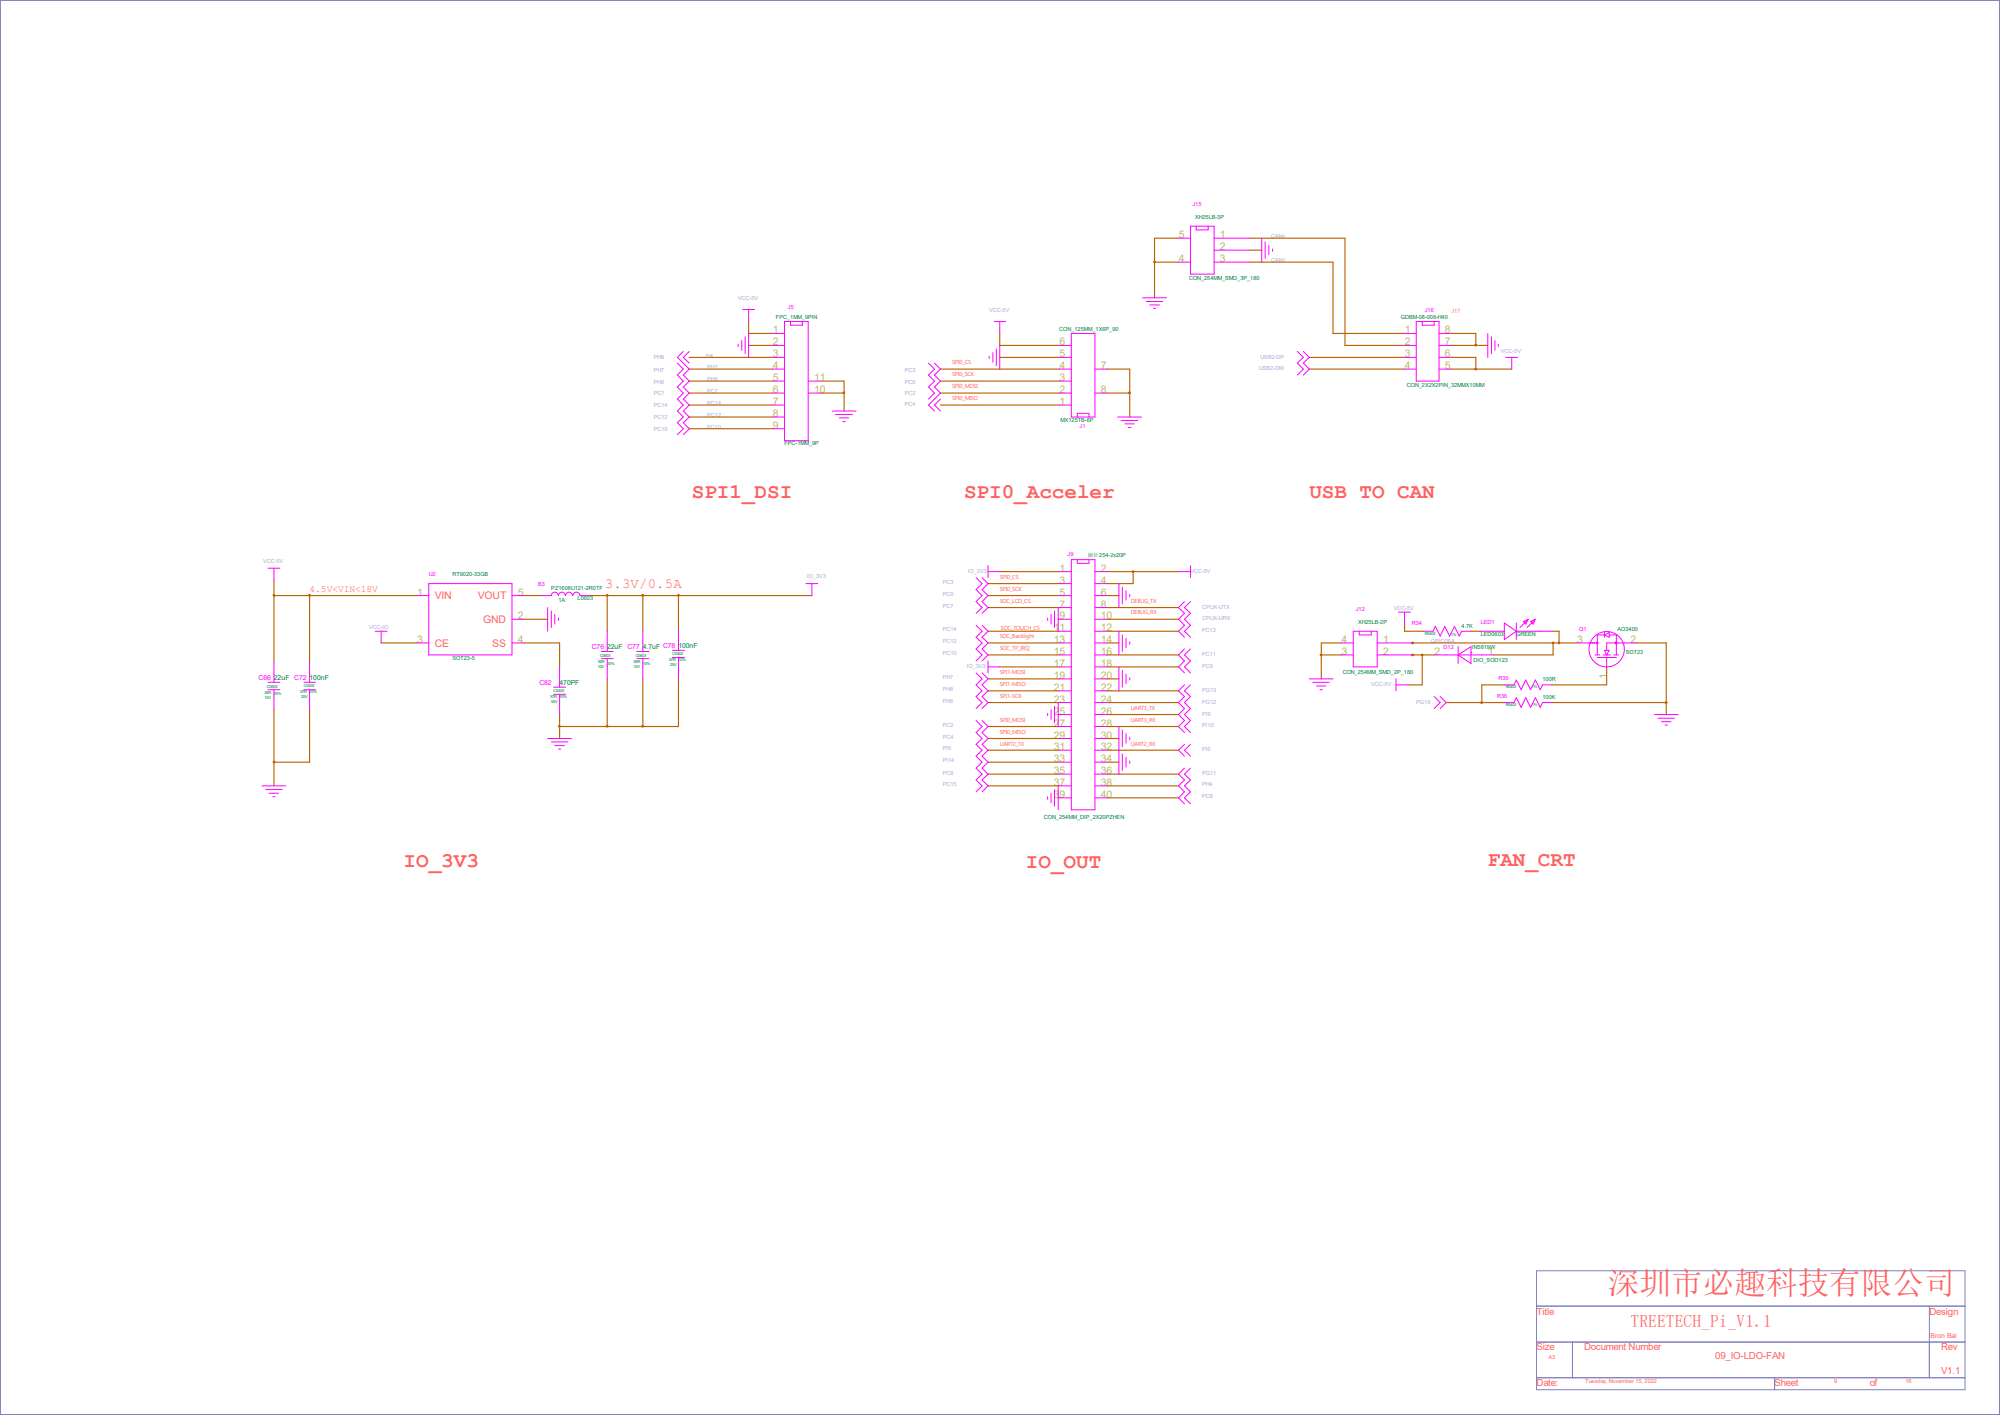
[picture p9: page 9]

Title TREETECH_Pi_V1.1 | Design

09_IO-LDO-FAN

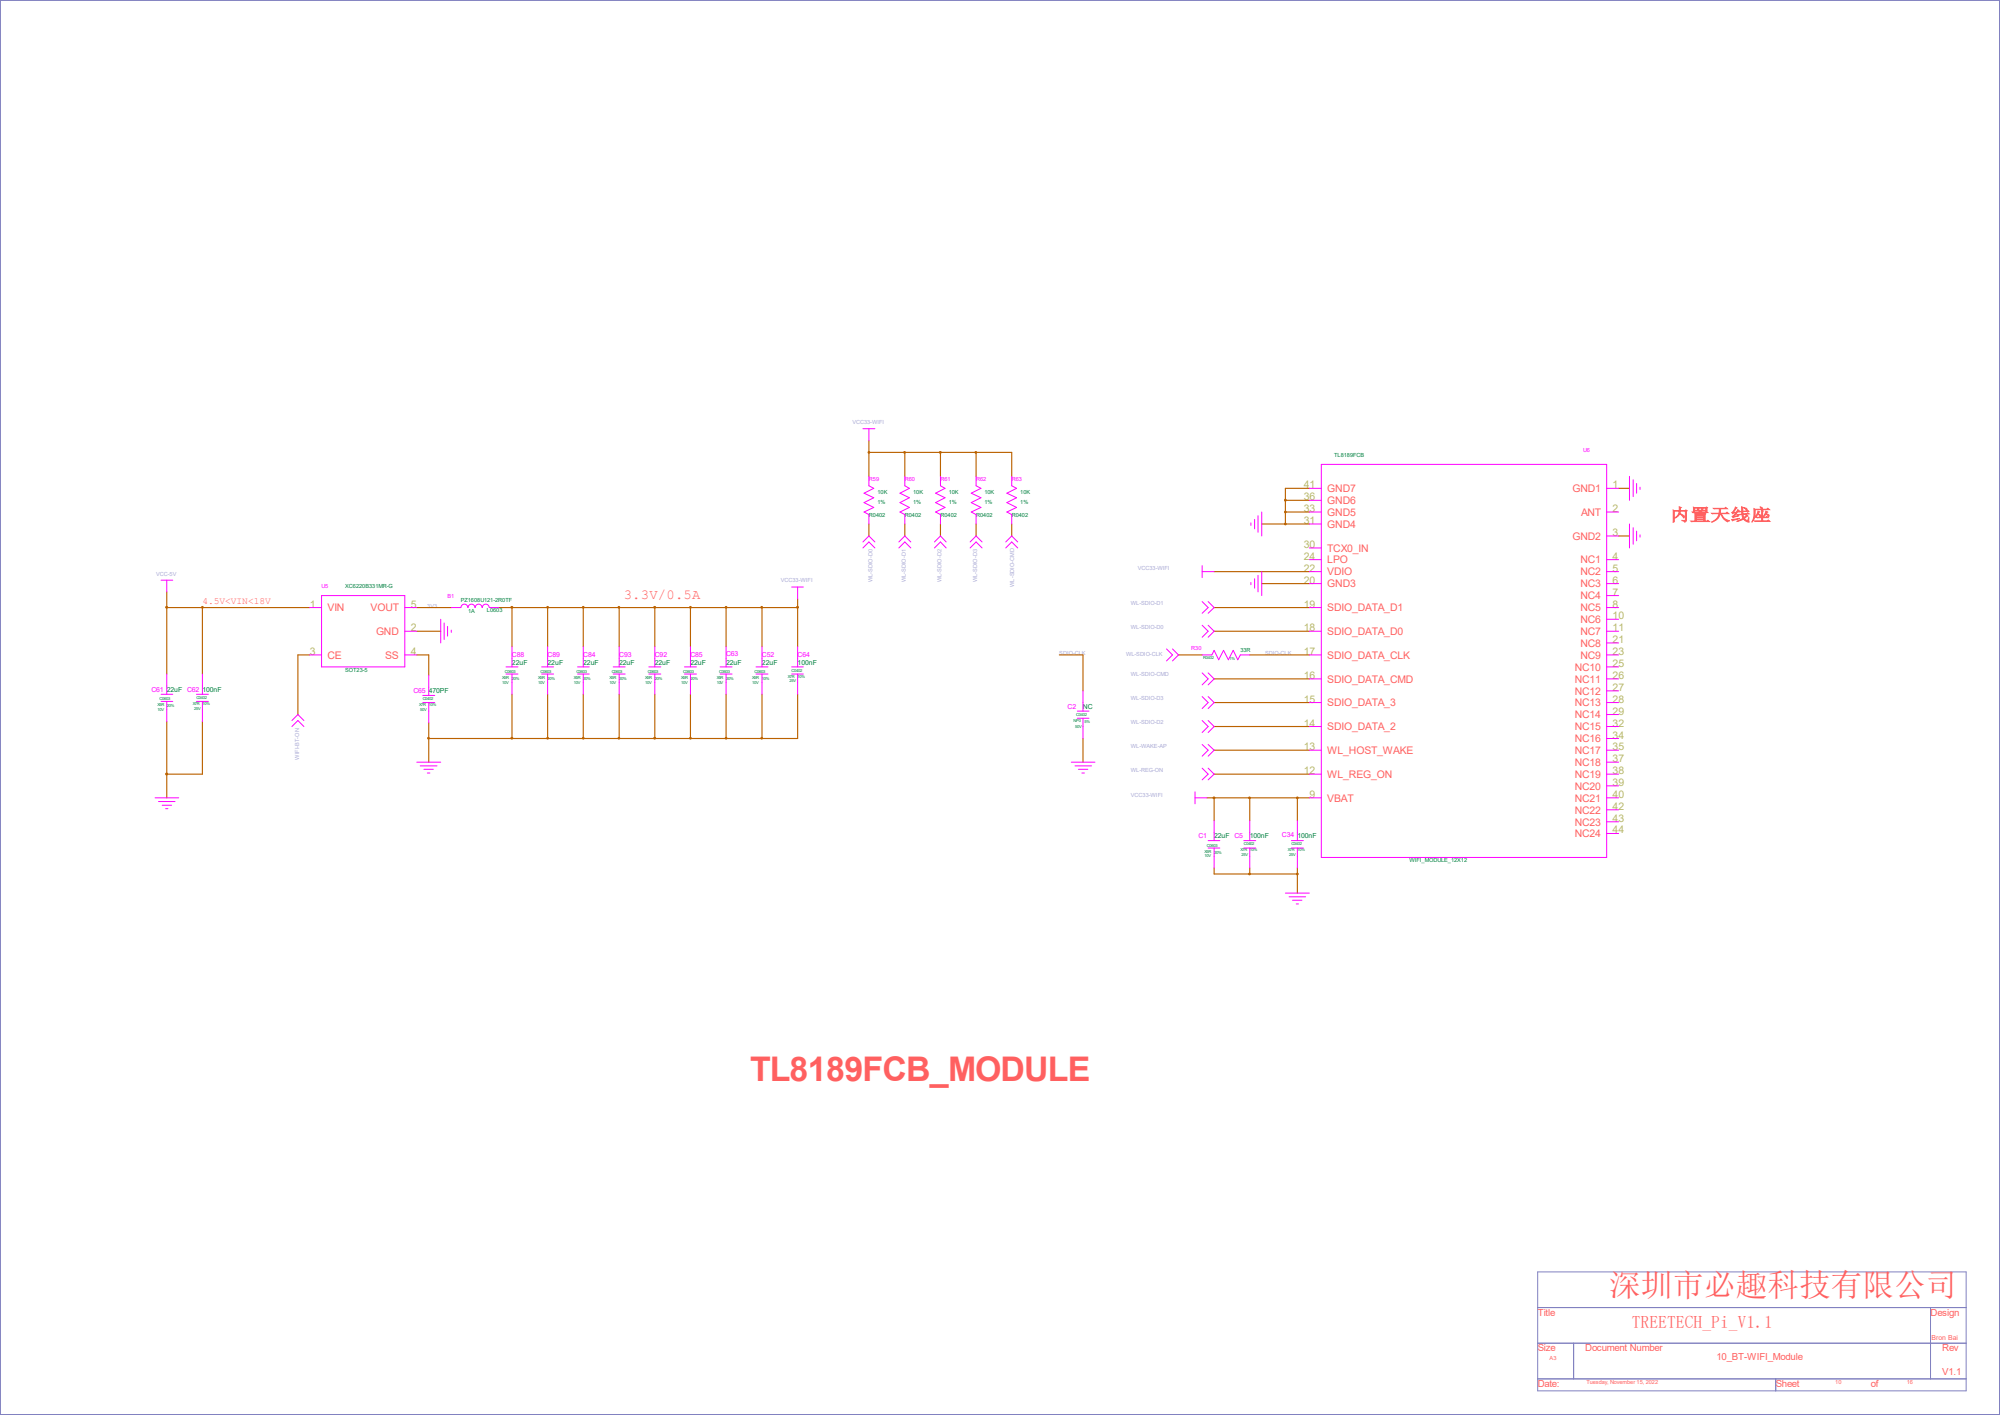
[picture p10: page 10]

Title TREETECH_Pi_V1.1 | Design

10_BT-WIFI_Module

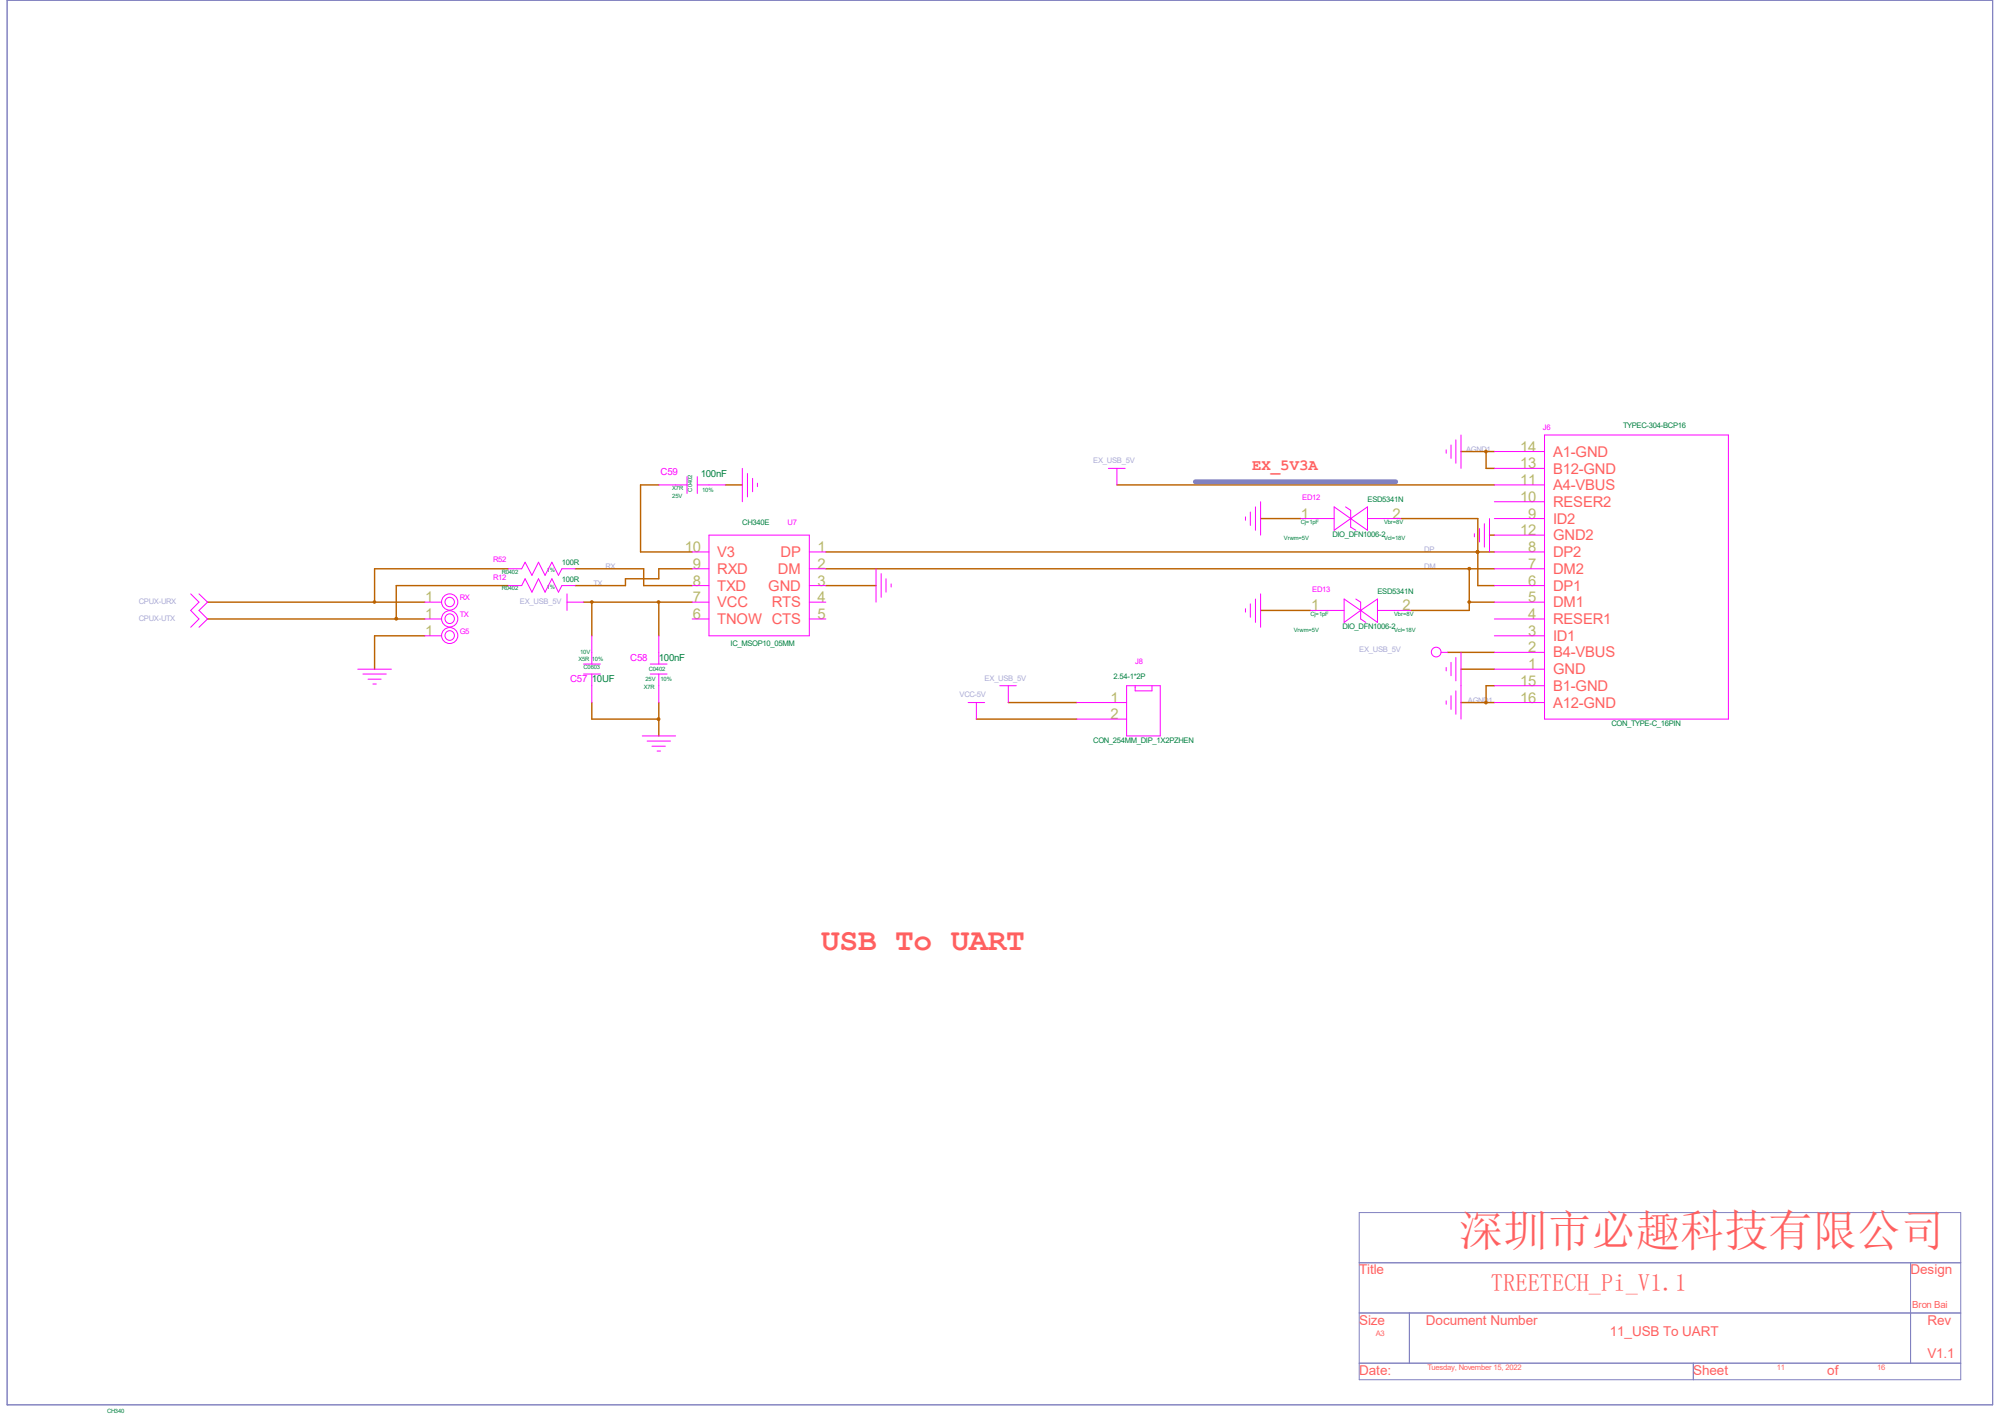
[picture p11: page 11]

Title TREETECH_Pi_V1.1 | Design

11_USB To UART

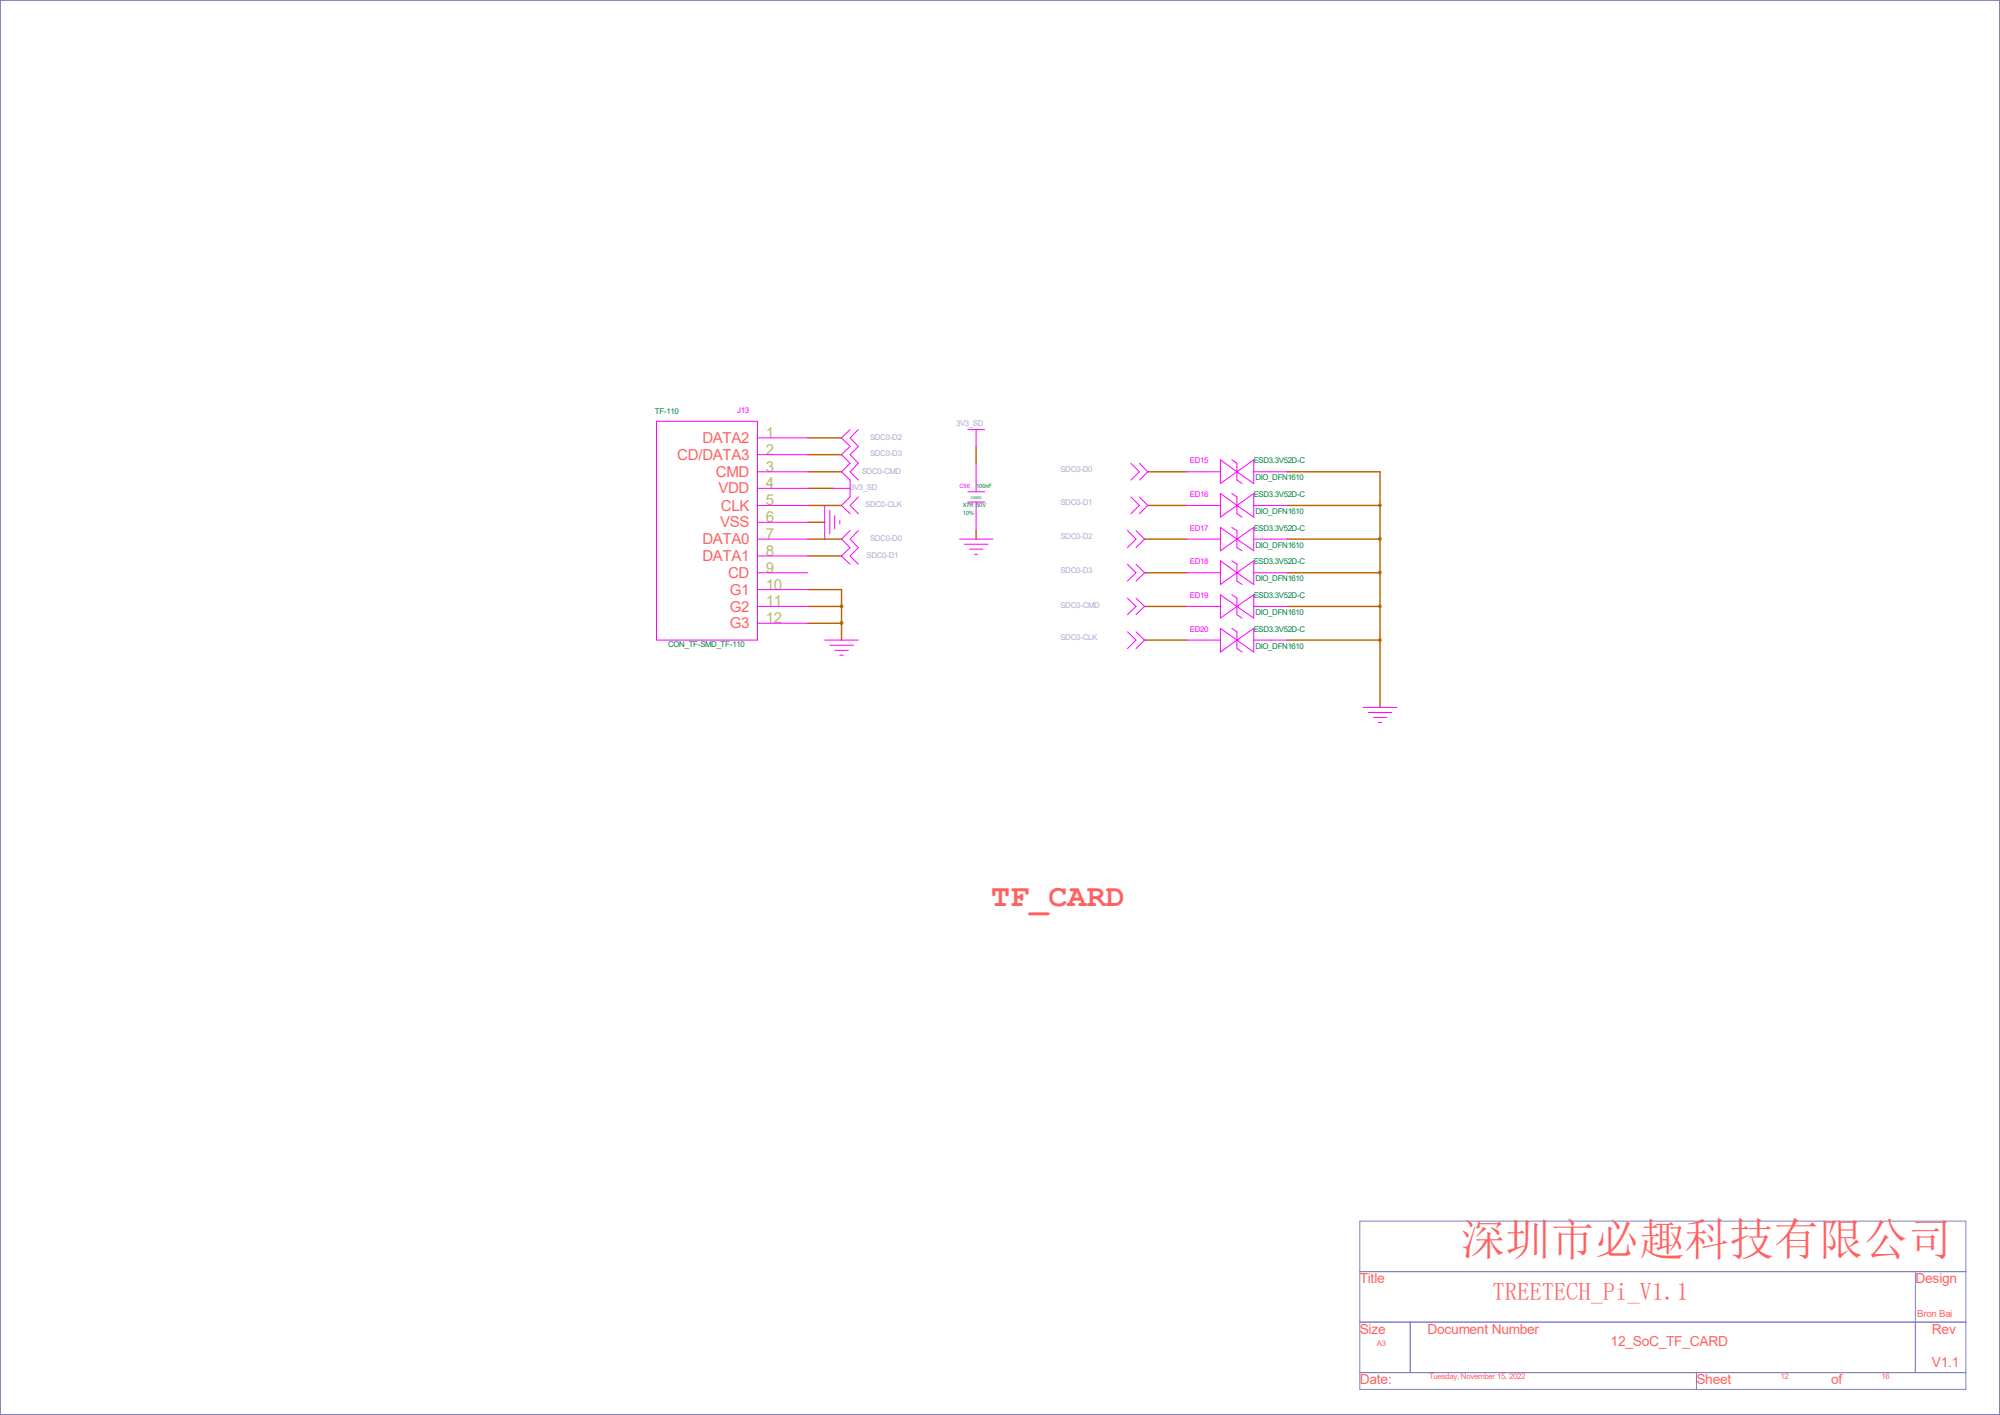
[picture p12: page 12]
SDC0-CLK; SDC0-D2; SDC0-D1; SDC0-D3; SDC0-CMD; SDC0-D0; 深圳市必趣科技有限公司; TF_CARD; CD/DATA3 CMD VDD CLK VSS DATA0 DATA1 CD G1; DATA2; DIO_DFN1610; ESD3.3V52D-C; CON_TF-SMD_TF-110

Title TREETECH_Pi_V1.1 | Design

12_SoC_TF_CARD

# Cj<=0.4pF

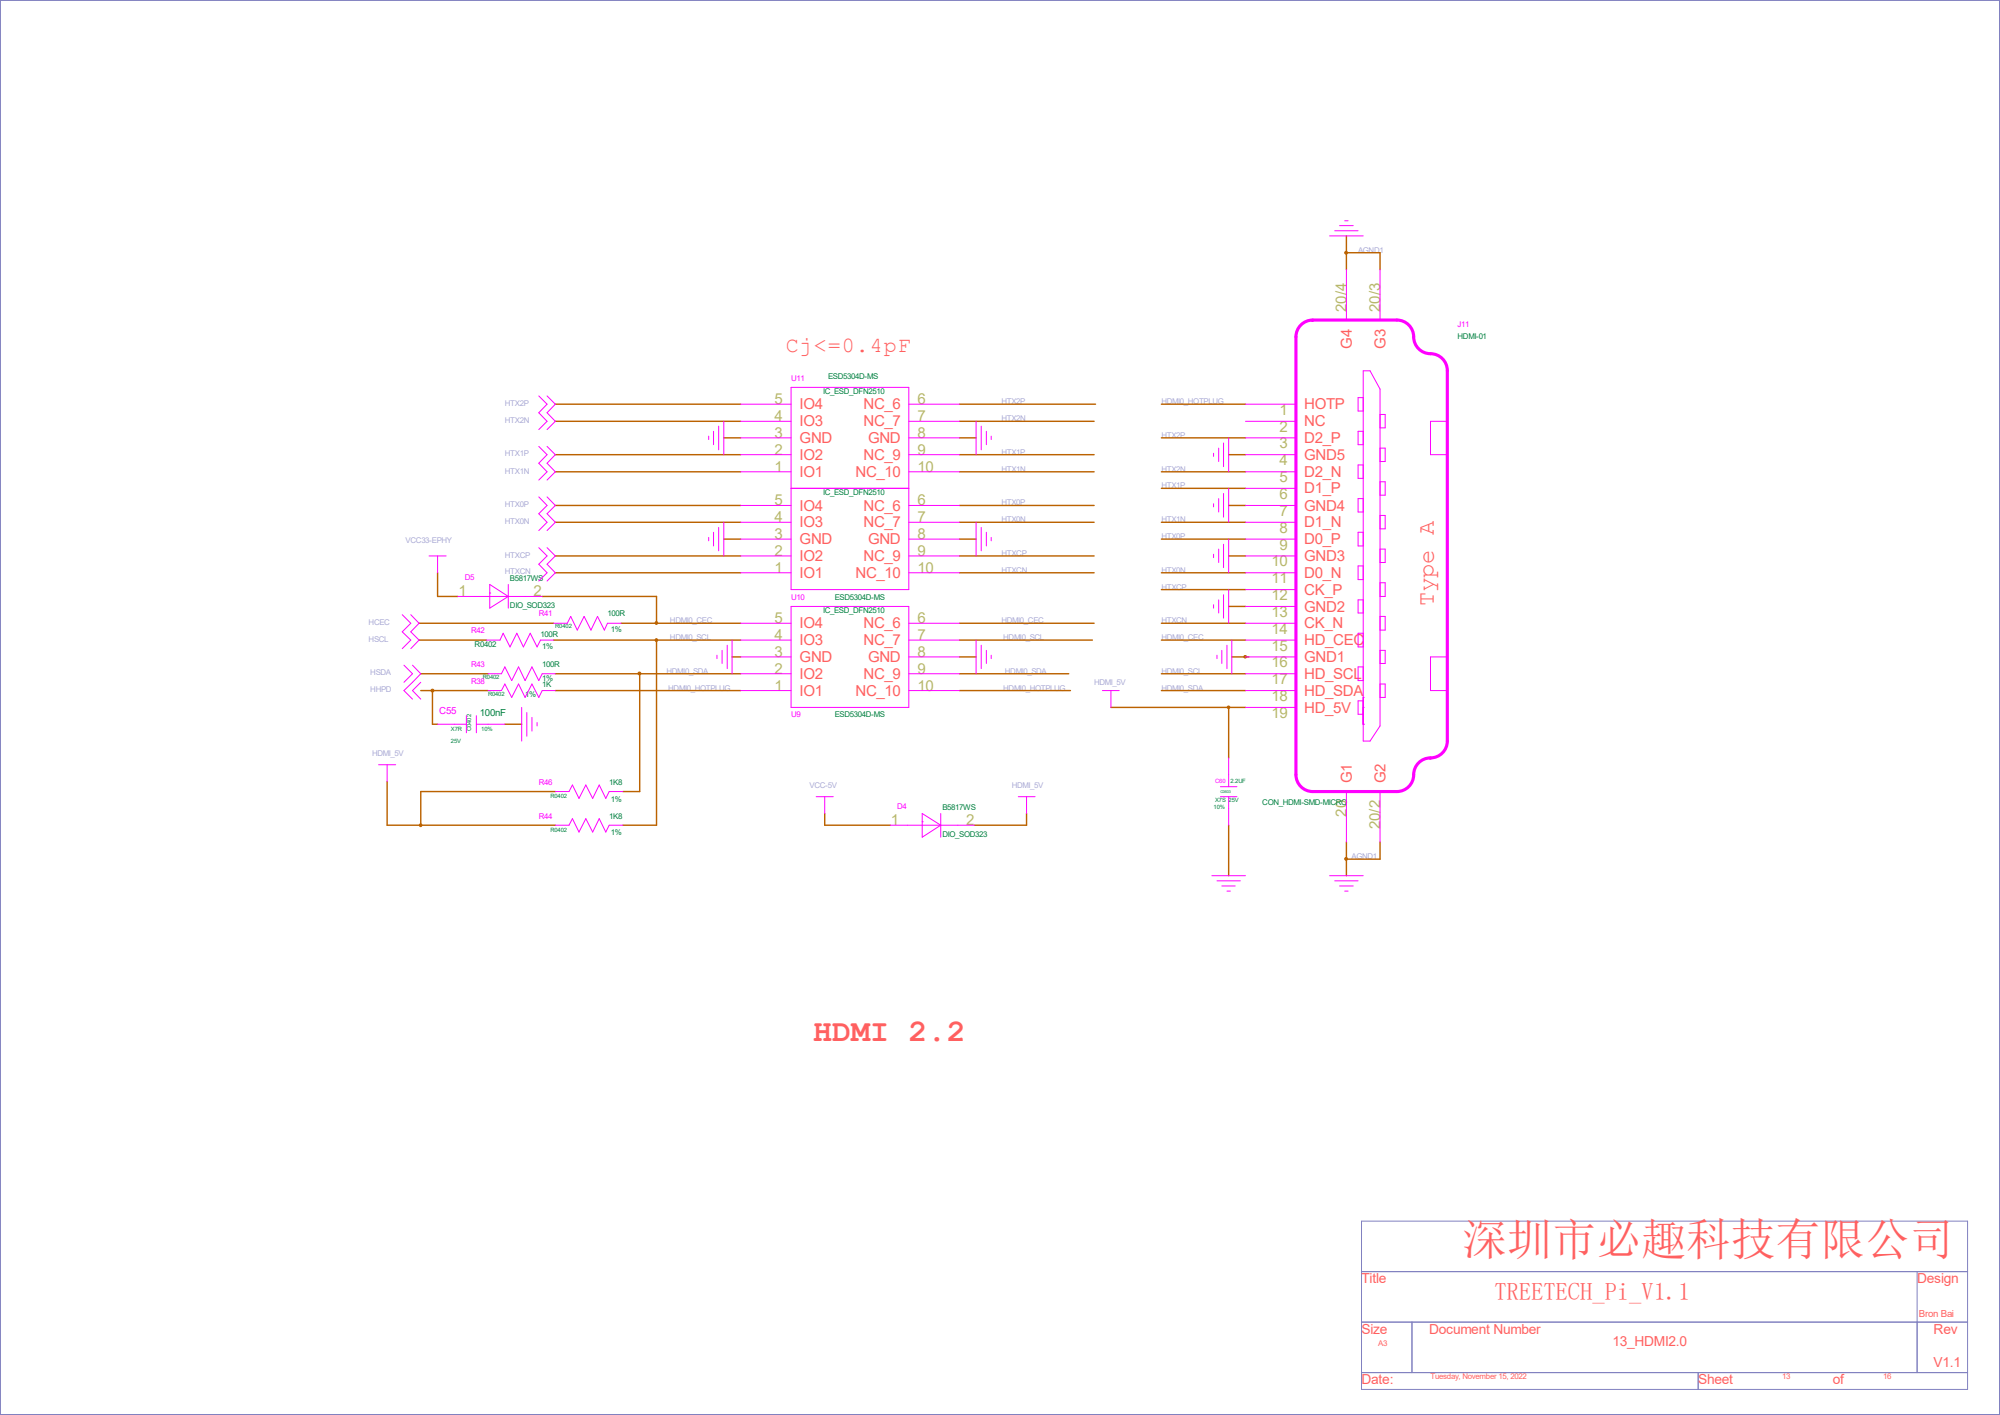
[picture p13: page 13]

Title TREETECH_Pi_V1.1 | Design

13_HDMI2.0

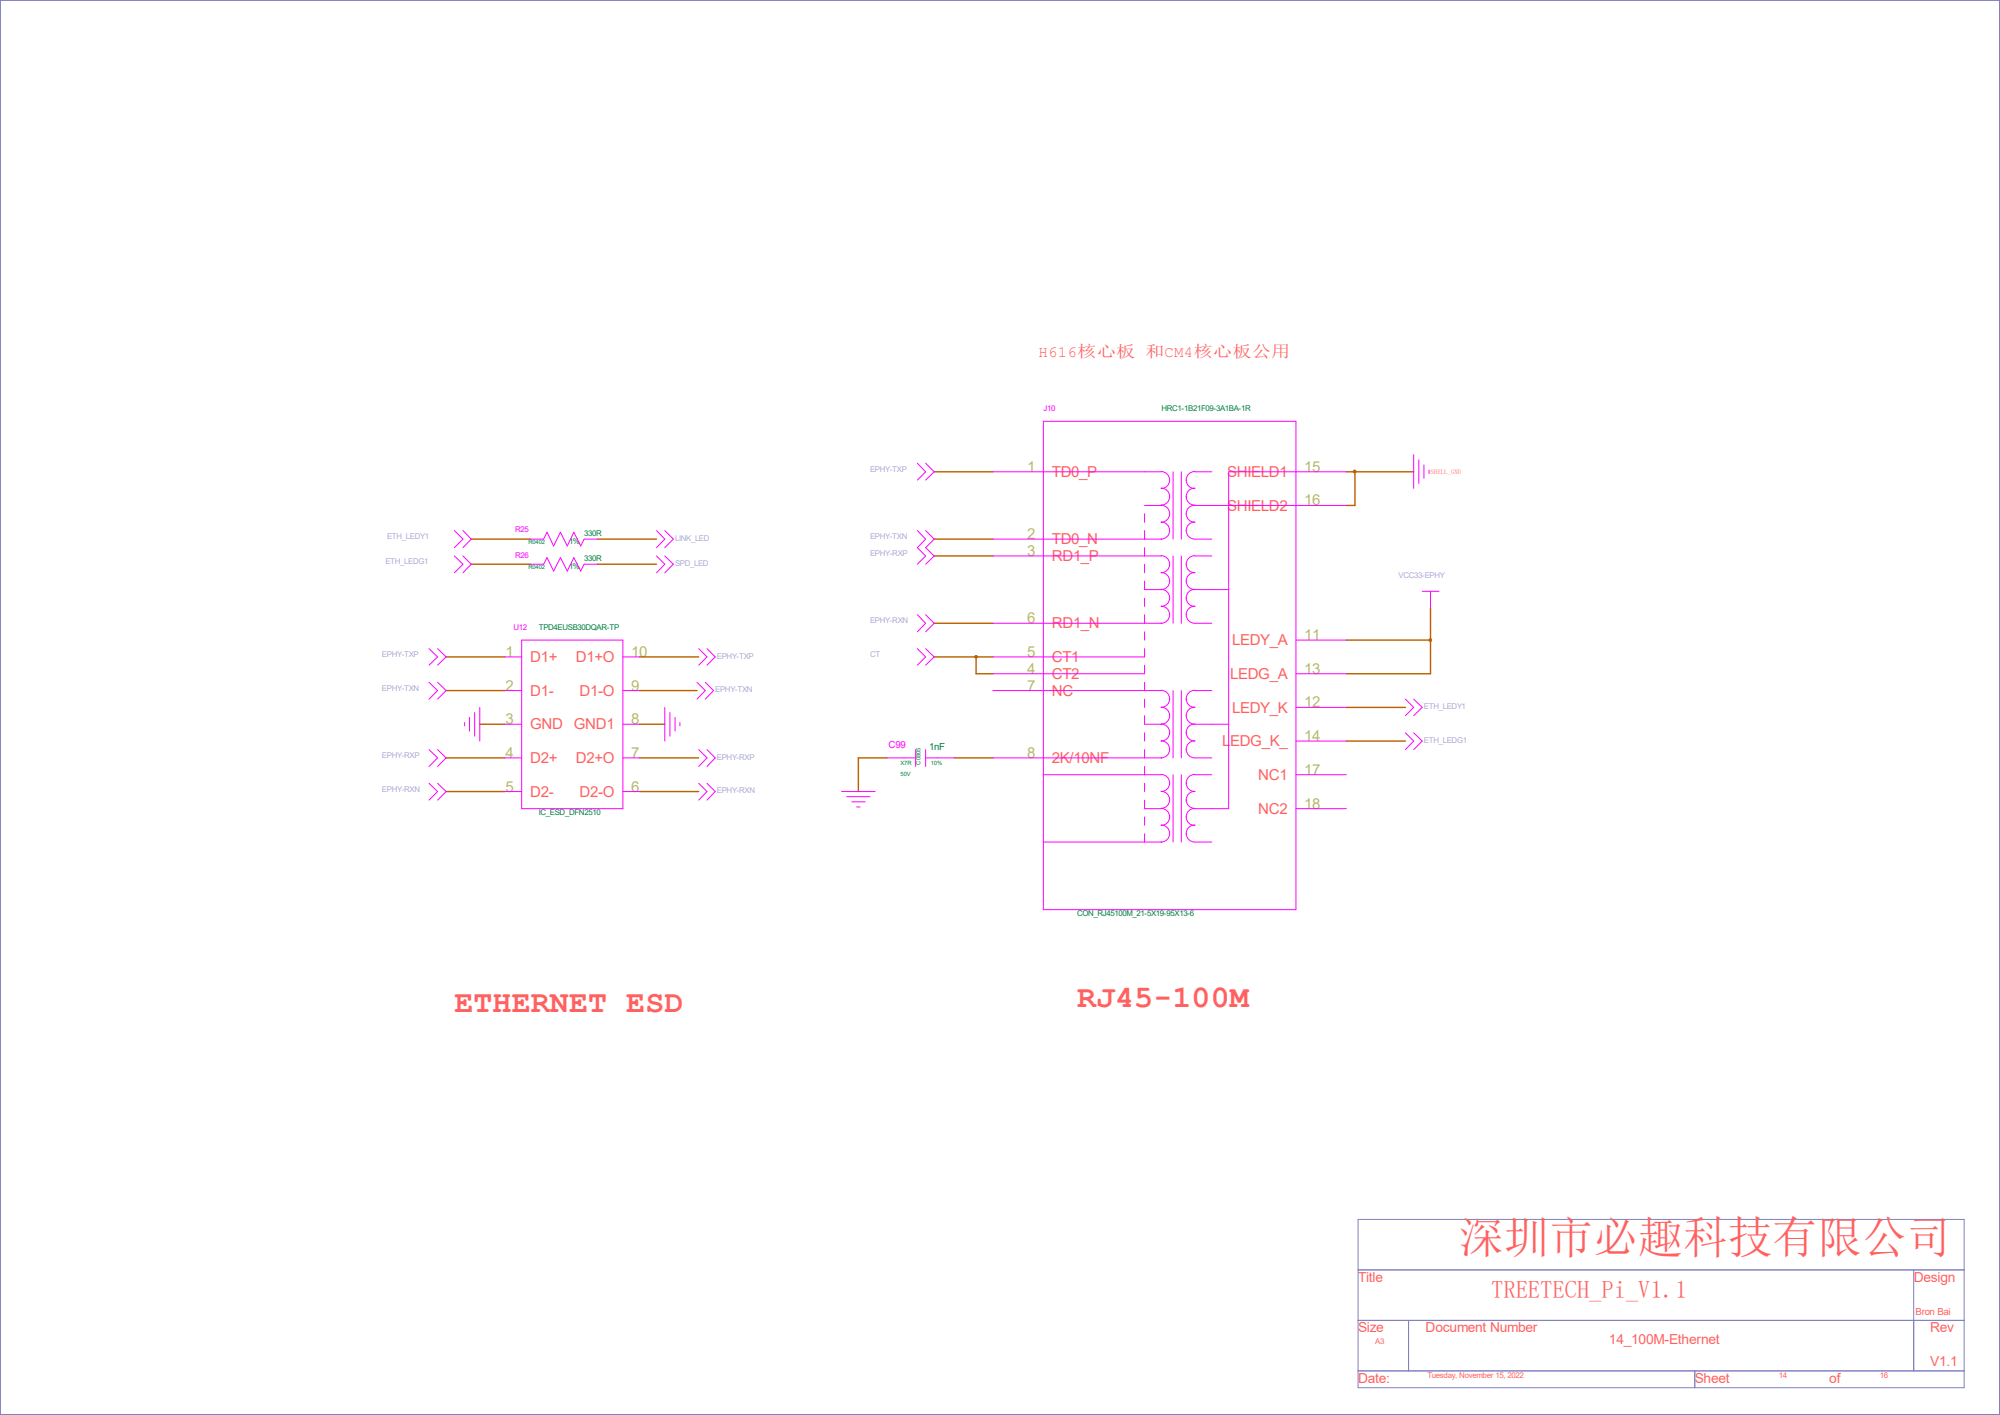
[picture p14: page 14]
VCC33-EPHY; LINK_LED; ETH_LEDG1; SPD_LED; EPHY-TXP; EPHY-TXN; EPHY-RXP; EPHY-RXN; ETH_LEDY1; 深圳市必趣科技有限公司; ETHERNET ESD; H616核心板 和CM4核心板公用; SHELL_GND; SHIELD1; LEDG_K_; SHIELD2; LEDY_K; LEDG_A; LEDY_A; GND; GND1; CON_RJ45100M_21-5X19-95X13-6; HRC1-1B21F09-3A1BA-1R; IC_ESD_DFN2510; TPD4EUSB30DQAR-TP

Title TREETECH_Pi_V1.1 | Design

14_100M-Ethernet

1 | 2
1 | 2

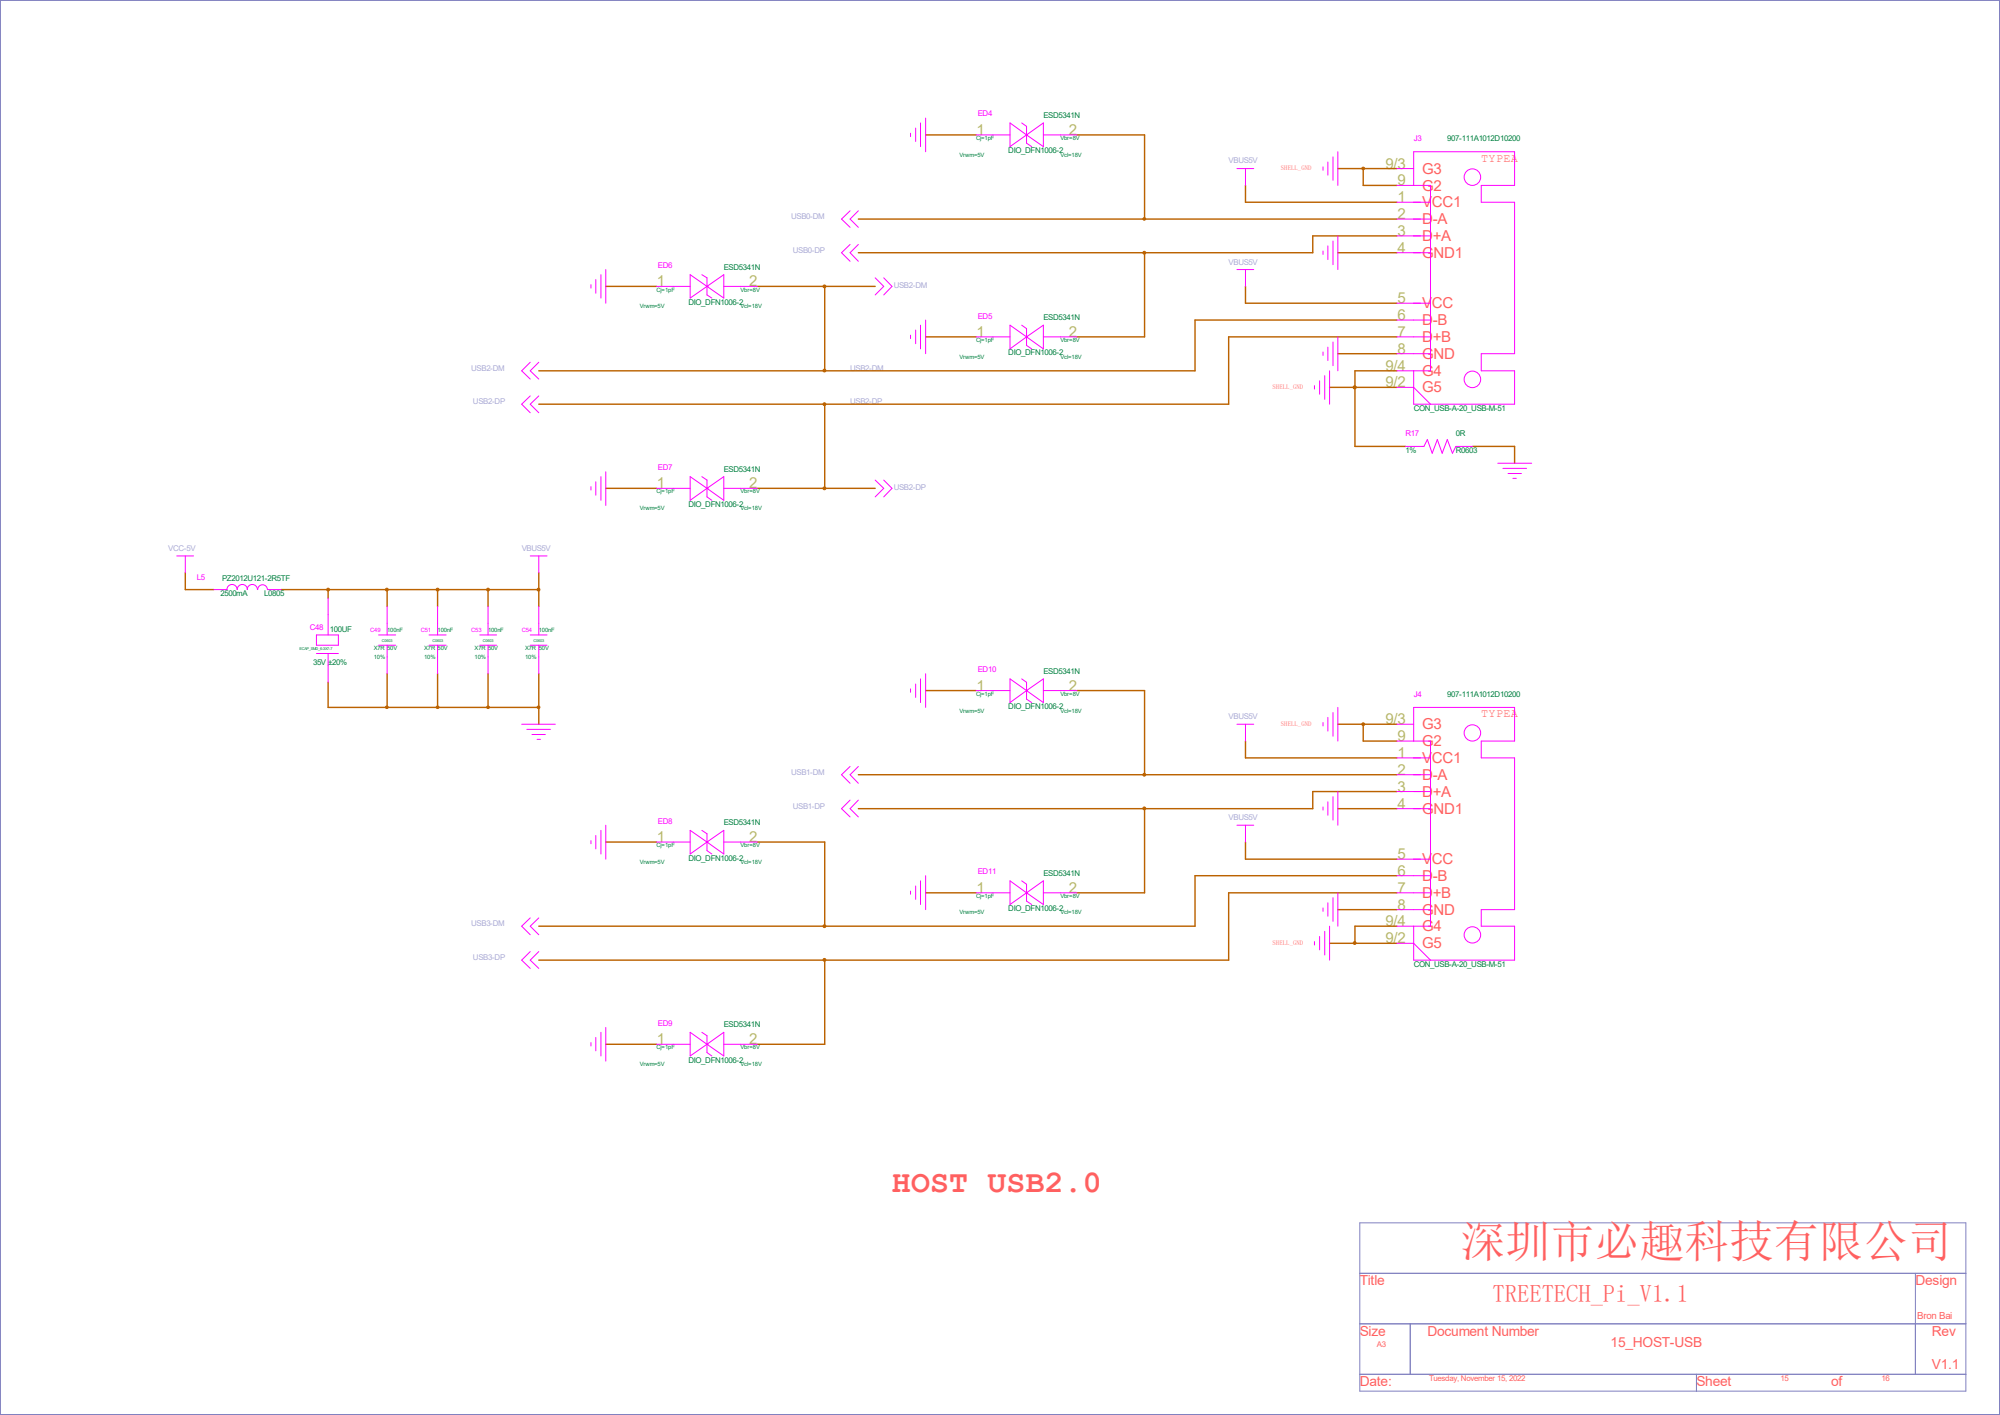
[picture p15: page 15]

Title TREETECH_Pi_V1.1 | Design

15_HOST-USB

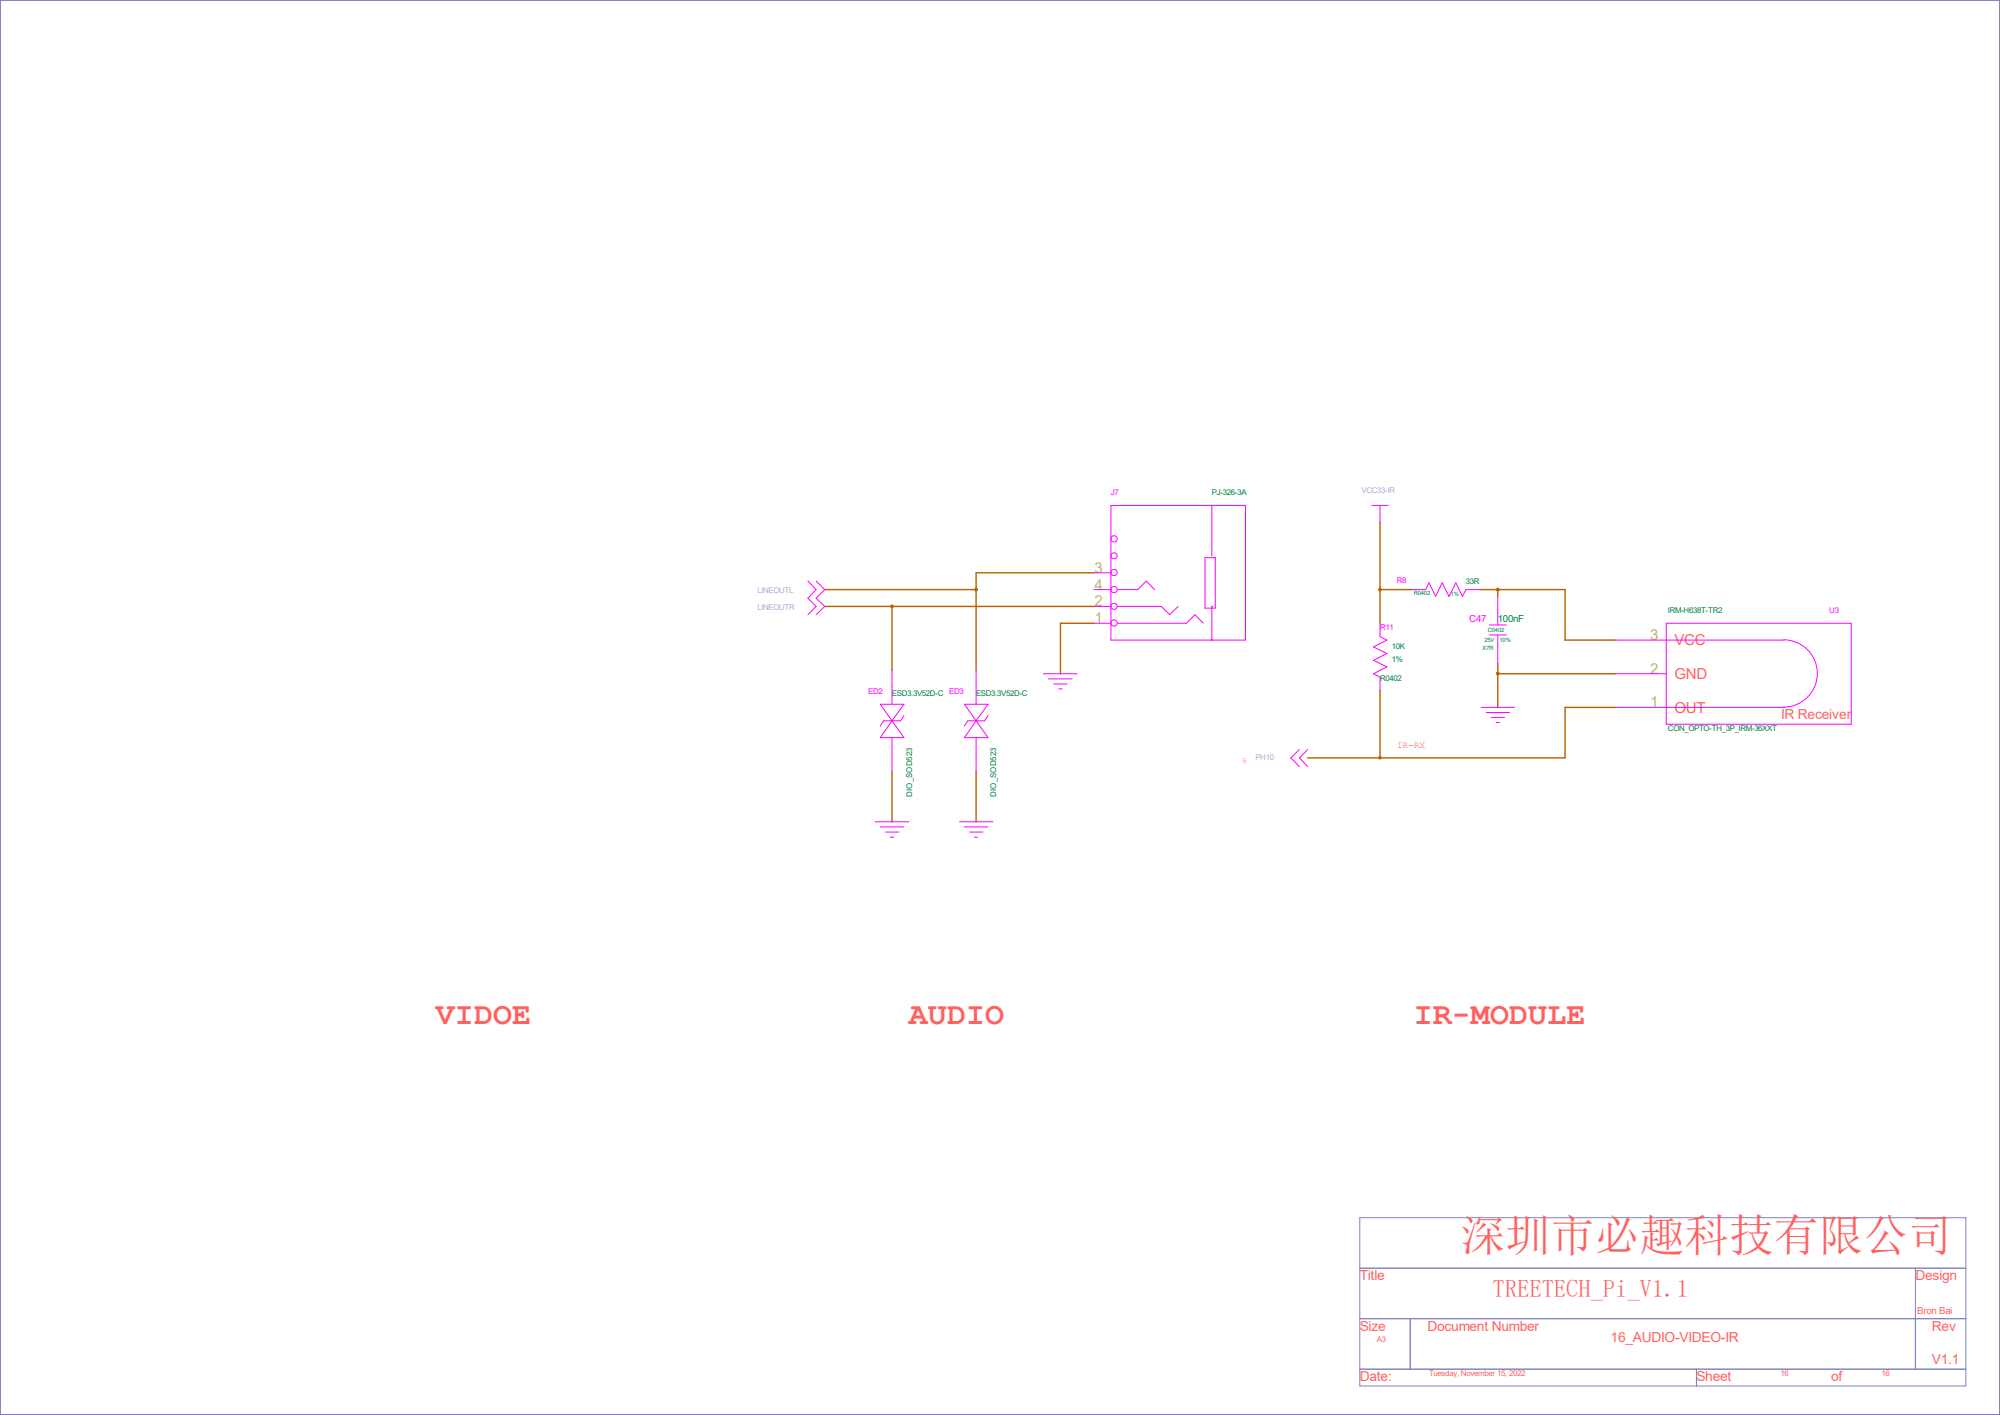
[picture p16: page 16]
VCC33-IR; LINEOUTL; LINEOUTR; 深圳市必趣科技有限公司; VIDOE; AUDIO; IR-MODULE; IR Receiver; VCC; OUT; GND; CON_OPTO-TH_3P_IRM-36XXT; IRM-H638T-TR2; DIO_SOD523; ESD3.3V52D-C

Title TREETECH_Pi_V1.1 | Design

16_AUDIO-VIDEO-IR

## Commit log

2023-05-12 add .step
    [bottom_case.STEP, bottom_case.STL, middle_case.STEP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]
2023-05-15 update manual for type-c power jumper
2023-05-23 BIGTREETECH Pi V1.2 - Board Fan Pin Configuration (#4)
    * Create BIGTREETECH Pi V1.2 - Board Fan Pin Configuration
2024-12-19 Update Fan Pin Link to Bigtreetech repo (#8)
    The past commit links to a user fork of this repo. Changed the link to keep everything in the official Bigtreetech repo.
